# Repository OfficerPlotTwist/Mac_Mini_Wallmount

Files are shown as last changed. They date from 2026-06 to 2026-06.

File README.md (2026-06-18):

# Mac Mini M4 Wall Mount

A parametric, 3D-printable wall mount for the **Apple Mac Mini M4 / M4 Pro** (127 × 127 × 50 mm chassis), authored in **OpenSCAD**.

The Mini mounts flat against the wall with the **Apple logo facing the room**; the intake base + power button face the wall, held off by a ¾″ standoff gap. It's rotated 90° so the port faces meet the side rails — back ports (3× Thunderbolt, HDMI, Ethernet, power) on one rail, front (2× USB‑C, headphone) on the other.

## Design highlights

- **Corner‑hugging frame** — four rounded corner pockets cup the Mini's 25 mm corners; flexible side rails with snap hooks retain it in Z (press‑in assembly).
- **Side‑rail port cutouts** — obround holes sized per connector, widened for rubber strain‑relief boots, with inter‑port webs auto‑clamped to ≥ 3 perimeters.
- **Ø88 mm central contact pad** with a wide bore, reaching the Mini's solid central base past the recessed cooling vents.
- **Organic "topology‑optimized" bracing** — tapered Bézier struts fan from the pad to the side rails and corners (thick at the anchors, thin mid‑span).
- **Discrete support shelves** — small chamfered ledges, each sitting on a strut, at the recessed‑perimeter height.
- **Power‑button access pocket** — ribs beneath the wall‑facing power button shortened so a finger/tool can reach it.
- Four wall screws in the open top/bottom segments (clear driver access), countersunk for #8 wood screws / drywall anchors.

Target: **Prusa MK4**, 0.4 mm nozzle / 0.2 mm layer, **PETG**. A structural check (≈ 0.85 kg Mini, SF 10) leaves the load‑bearing wall at ~1.6 % of yield — the printed structure is far stronger than needed; wall anchors are the real limit.

## Files

| Path | What |
|---|---|
| `macmini_wall_mount.scad` | Parametric source (always the latest design) |
| `macmini_wall_mount.stl`  | Latest rendered mesh |
| `Macmini.glb` | Reference Mac Mini model (stylized — verify dims against a real unit) |
| `versions/` | Snapshots (`vNN_*.scad` + `.stl`), `thumbs/`, and `VERSIONS.md` change log |

## Build

```sh
openscad -o macmini_wall_mount.stl macmini_wall_mount.scad
```

Key parameters live at the top of the `.scad` (fit, standoff gap, wall thickness, port lists, strut/shelf controls, power‑button location). See `versions/VERSIONS.md` for the design evolution.

> **Before printing:** port positions and the power‑button location come from a *stylized* reference GLB — verify against your actual Mac Mini, and set `ridge_lift` to the measured perimeter recess depth.

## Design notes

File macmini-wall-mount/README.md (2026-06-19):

# Mac Mini M4 Wall Mount

A parametric, 3D-printable wall mount for the **Apple Mac Mini M4 / M4 Pro** (127 × 127 × 50 mm chassis), authored in **OpenSCAD**.

The Mini mounts flat against the wall with the **Apple logo facing the room**; the intake base + power button face the wall, held off by a ¾″ standoff gap. It's rotated 90° so the port faces meet the side rails — back ports (3× Thunderbolt, HDMI, Ethernet, power) on one rail, front (2× USB‑C, headphone) on the other.

## Design highlights

- **Corner‑hugging frame** — four rounded corner pockets cup the Mini's 25 mm corners; flexible side rails with snap hooks retain it in Z (press‑in assembly).
- **Side‑rail port cutouts** — obround holes sized per connector, widened for rubber strain‑relief boots, with **45° teardrop tops** (self‑supporting when printed back‑plate‑down — no droopy overhangs) and inter‑port webs auto‑clamped to ≥ 2.0 mm (~4–5 perimeters, so the crowded back‑rail webs don't snap).
- **Ø88 mm central contact pad** with a wide bore, reaching the Mini's solid central base past the recessed cooling vents.
- **Organic "topology‑optimized" bracing** — tapered Bézier struts fan from the pad to the side rails and corners (thick at the anchors, thin mid‑span).
- **Discrete support shelves** — small chamfered ledges, each sitting on a strut, at the recessed‑perimeter height.
- **Power‑button access pocket** — ribs beneath the wall‑facing power button shortened so a finger/tool can reach it.
- Four wall screws in the open top/bottom segments (clear driver access), countersunk for #8 wood screws / drywall anchors.

Target: **Prusa MK4**, 0.4 mm nozzle / 0.2 mm layer, **PETG**. A structural check (≈ 0.85 kg Mini, SF 10) leaves the load‑bearing wall at ~1.6 % of yield — the printed structure is far stronger than needed; wall anchors are the real limit.

## Files

| Path | What |
|---|---|
| `macmini_wall_mount.scad` | Parametric source (always the latest design) |
| `macmini_wall_mount.stl`  | Latest rendered mesh |
| `Macmini.glb` | Reference Mac Mini model (stylized — verify dims against a real unit) |
| `versions/` | Snapshots (`vNN_*.scad` + `.stl`), `thumbs/`, and `VERSIONS.md` change log |

## Build

```sh
openscad -o macmini_wall_mount.stl macmini_wall_mount.scad
```

Key parameters live at the top of the `.scad` (fit, standoff gap, wall thickness, port lists, strut/shelf controls, power‑button location). See `versions/VERSIONS.md` for the design evolution.

> **Before printing:** port positions and the power‑button location come from a *stylized* reference GLB — verify against your actual Mac Mini, and set `ridge_lift` to the measured perimeter recess depth.

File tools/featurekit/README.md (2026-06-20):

# featurekit

Feature-first CAD engine. Declare a part as an ordered list of named features
(each `add` or `cut`, each with a stable id and deterministic color); generate
a fused printable STEP plus a colored, labeled feature-view assembly + manifest
sidecar for the CAD Viewer's Feature Legend panel.

## Usage

```python
from pathlib import Path
from build123d import Box, Cylinder
from featurekit import Feature, Part, generate

p = Part("plate")
p.add(Feature(id="base_plate", name="Base plate", kind="add", build=lambda: Box(20, 20, 4)))
p.add(Feature(id="vent_hole", name="Vent hole", kind="cut", build=lambda: Cylinder(3, 10)))

generate(p, stem=Path("models/plate"))
# -> models/plate.step (fused, printable)
#    models/plate.features.step (colored feature-view assembly)
#    models/plate.features.step.js (legend manifest sidecar)
```

## Dev setup

```bash
pip install -r tools/featurekit/requirements.txt   # build123d for geometry
python -m pytest tools/featurekit/tests -v
```

Geometry tests are skipped automatically when build123d is not installed.

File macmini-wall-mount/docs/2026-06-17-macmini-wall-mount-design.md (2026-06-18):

# Mac Mini (M4 / M4 Pro) Wall Mount — Design Spec

**Date:** 2026-06-17
**Author:** Claude + supercoolraydude@gmail.com
**Target hardware:** Apple Mac Mini 2024 (M4 / M4 Pro) — shared 127 × 127 × 50 mm chassis
**Output:** One parametric OpenSCAD file → STL → PrusaSlicer (MK4) → printed in ASA

---

## 1. Goal

A single-piece, wall-mounted cradle that holds the Mac Mini **flat against the wall** while leaving the **rear ports + exhaust, the front ports, the bottom air intake, and the power button all usable**. Screw-mounts to the wall. No screw/VESA holes exist on the Mini, so retention is purely mechanical (edge capture).

## 2. Verified hardware facts

| Fact | Value | Source |
|---|---|---|
| Footprint | 127 × 127 mm (5 × 5 in) | Apple spec; GLB aspect ratio confirms 2.54:1 |
| Height | 50 mm (2 in) | Apple spec |
| Weight | ~0.67–0.73 kg | Apple spec |
| Back ports | power, Ethernet, HDMI, 3× Thunderbolt 4 | MacRumors / OWC |
| Front ports | 2× USB-C, headphone jack | MacRumors / OWC |
| Power button | **underside, rear-left corner** | MacRumors |
| Air intake | ring on the **bottom** face (perimeter of central base puck) | Apple design |
| Exhaust | out the **back** face | Apple design |
| Corner radius | **25 mm** (≈77 mm flat per side) | measured from `Macmini.glb`, all 4 corners |

The supplied `Macmini.glb` is geometrically a true Mac Mini but at an arbitrary scale (~38 units/m); it is **reference-only**. All dimensions come from Apple's published figures and are parameterized.

## 3. Orientation (locked)

Mini mounted flat against the wall:

- **Top / Apple-logo face → faces the room** (clean appearance).
- **Bottom face (intake + power button) → toward the wall**, held off the backplate by a central standoff.
- **Back edge (6 ports + exhaust) → faces DOWN** — cables route straight down the wall; exhaust vents downward.
- **Front edge (USB-C + headphone) → faces UP** — front ports remain reachable.
- **Standoff gap ≈ 28 mm** between bottom face and backplate: feeds the intake ring and gives whole-finger access to the power button.

### Coordinate convention (as mounted, viewer in the room)
- **+X** = viewer's right, **+Y** = up, **+Z** = out of wall toward viewer.
- Wall plane = XY at Z = 0 (backplate face).
- Derived power-button location: bottom face, **down edge (−Y), viewer's-right (+X) corner**, on the wall side. (Original rear-left maps to mounted lower-right after the logo-to-room / back-edge-down rotation. **To be confirmed against the physical unit**; position is parametric.)

```
 FRONT (from the room)                 SIDE (cross-section, gravity ↓)
 ┌───────────────────────┐ ← UP: front   wall│        room→
 │ o   ┌───────────┐   o │  USB-C+phones     │┌──┐
 │     │  ▲ Apple   │     │  (open)        B  │↕ ││M │ ← top/logo→room
 │     │   logo     │     │  ←L/R rails    P  │28││I │
 │     │(top face) │     │   +return lip  L  │mm││N │
 │ o   └───────────┘   o │ ← DOWN: back   E  │↕ ││I │ ← bottom face→wall
 └──────[button≈lower-R]─┘  ports+exhaust    │ s└──┘
   o = wall screw holes      (open)           standoff in gap
```

## 4. Part breakdown (single printed piece)

1. **Backplate** — flat plate against the wall. 4 countersunk screw holes (corners) for #8 wood screws / drywall anchors. Lightened/vented where it doesn't weaken the screw bosses. Thickness ~4–5 mm.
2. **Central standoff boss** — raised pad (height = gap ≈ 28 mm) contacting **only the Mini's central base puck**, never the intake ring. Sets the airflow/finger gap.
3. **Rounded capture frame** — full-height side walls conforming to the Mini's rounded corners (corner hug + in-plane retention incl. ~0.7 kg weight). The **top & bottom port edges are opened nearly corner-to-corner (~114 mm)** — independent of `corner_r` — because the back ports span almost the full width; only small corner nubs remain. The rounded-corner cut removes the arc material in front of the outer ports too.
4. **Side snap hooks** — on the flexible left & right straight rails, a **~2 mm flat catch** with a 45° self-supporting top, retaining the Mini in Z (pull-off). Rails **vented at gap level** for side airflow.
5. **Assembly** — press the Mini straight in toward the wall: corners drop into their pockets, side rails flex, hooks snap over the top-face edge.
6. **Power-button access** — lower-right, reached through the open bottom edge + 28 mm gap (wall-side gap kept clear there).
7. **Open zones (must stay clear):** full top/logo face; front ports (up edge); back ports + exhaust (down edge); intake gap behind; power button (lower-right).

## 5. Parameters (OpenSCAD variables, with defaults)

| Param | Default | Notes |
|---|---|---|
| `mini_w` | 127 | Mini width (X) |
| `mini_h` | 127 | Mini height (Y) |
| `mini_t` | 50 | Mini thickness (Z, wall→room) |
| `corner_r` | 25 | Mini rounded-corner radius (measured from GLB) |
| `port_post` | 7 | structure kept at each end of the open port edges; **sets the port-opening width** (= `mini_w + 2*fit − 2*port_post` ≈ 114 mm) independent of `corner_r` |
| `fit` | 0.4 | per-side clearance |
| `gap` | 28 | standoff height (intake + button access) |
| `lip_flat` | 2.0 | side-hook flat catch depth |
| `wall_th` | 3.2 | capture-wall thickness |
| `back_th` | 4.5 | backplate thickness |
| `ear` | 16 | side screw-ear width |
| `screw_d` | 4.5 | clearance for #8 screw shank |
| `head_d` | 9 | countersink head dia |
| `vent` | true | side-rail venting on/off |

## 6. Thermal rationale

- **Intake:** bottom ring draws from the 28 mm gap, fed by the open up edge, open down edge, and vented side rails — unobstructed.
- **Exhaust:** out the down edge, directed away from the cradle; minimal recirculation since intake is fed primarily from the up/side edges.
- **Material:** **ASA** (heat-tolerant, already in the user's filament stock). **PLA is rejected** — softens near the warm exhaust.

## 7. Print settings (target)

- Printer: Prusa MK4 (IS), 0.4 mm nozzle, 0.2 mm layers (matches existing prints on the USB).
- Orientation: backplate flat on the bed (+Z = out of wall); lips printed as chamfered overhangs → **no supports**.
- Material: ASA. Perimeters ≥ 3, infill ≥ 20% for rigidity at the rails.

## 8. Acceptance criteria

1. Mini slides in and is retained against pull-off and against sliding down (weight held).
2. All rear ports + exhaust accessible/unobstructed (down edge).
3. Both front ports + headphone accessible (up edge).
4. Bottom intake ring unobstructed; ≥ 28 mm clear gap to backplate.
5. Power button reachable without removing the Mini.
6. Mounts to wall via 4 screws; sits flat.
7. STL renders cleanly from the `.scad` (manifold, no errors) and slices support-free in PrusaSlicer.
8. Top/logo face fully visible except thin perimeter lips.

## 9. Open items / to verify

- **Power-button exact corner** — confirm lower-right mapping against the physical Mini before printing; adjust `pb_x/pb_y`.
- **Intake ring inner/outer diameter** — confirm the standoff pad stays inside the central puck and never caps the ring; refine pad diameter on first test print.
- **Fit clearance** — 0.4 mm nominal; validate with a corner test print before committing to the full part.

## 10. Toolchain

- **OpenSCAD** (installed via winget this session) authors `macmini_wall_mount.scad`.
- Render: `openscad -o macmini_wall_mount.stl macmini_wall_mount.scad`.
- Slice/print: PrusaSlicer → MK4, ASA profile.

---

*Note: working directory is not a git repository, so this spec is written to disk but not committed. Run `git init` to version it if desired.*

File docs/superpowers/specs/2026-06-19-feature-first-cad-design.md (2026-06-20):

# Feature-First CAD with a Live Legend Viewport — Design Spec

**Date:** 2026-06-19
**Status:** Draft for review
**Scope:** Modules 0–2 (manifest contract, `featurekit` generator + naming-rigor
enforcement, viewer Feature Legend panel + live-refresh).
**Explicitly out of scope:** any Mac Mini–specific port or part-specific content.
This spec delivers the reusable engine + viewer only.

Companion methodology:
[`docs/methodology/part-separation-vs-merged-whole.md`](../../methodology/part-separation-vs-merged-whole.md).

## 1. Problem

Today CAD parts are authored as a **merged whole**: every addition and removal is
fused into one anonymous solid (OpenSCAD `union`/`difference`, or the `cad`
skill's "one valid solid" STEP). After generation, individual features
(backplate, standoff, frame, port cuts…) are not addressable — they cannot be
colored, named, isolated, reviewed independently, or owned by separate agents.

We want an iterative **text-to-CAD** workflow where each feature is **distinct
geometry**: named, deterministically colored, individually isolatable, with
removals shown as translucent ghost cutters — all in a **continually-open
viewport** with a docked legend (color → name key) that **refreshes in place** as
the user iterates by text, while the real exported part stays a single printable
solid.

## 2. Decisions (locked)

| Decision | Choice |
|---|---|
| Authoring toolchain | build123d → STEP, on top of the installed `cad`/`cadpy` engine |
| Feature ↔ part relationship | **Viz layer over one fused part** (fused solid is the print source of truth) |
| Subtractive features | **Translucent ghost cutters** — each removal is its own colored, labeled solid in the feature view |
| Viewport interactivity | **Custom Feature Legend panel** (Approach B), built in upstream viewer source |
| Legend location | **Docked under the render**, following the existing file-sheet visual language |
| Ghost styling | **Feature-identity color is primary** (each feature its own stable hue); cuts rendered translucent/x-ray and tagged `cut` in the legend. Revisitable. |
| Viewer source | Build against upstream **`earthtojake/text-to-cad`** (`main`, top-level `viewer/`); rebuild `dist` and sync into the local skill runtime |
| Naming | **Enforced at generation time** (a gate, not a guideline) |

## 3. Architecture

Three modules joined by one contract (the Feature Manifest). Each module is
independently understandable and testable.

```
 author (Python)                generate                         view (browser)
┌────────────────┐   featurekit   ┌──────────────────────┐  cad-viewer  ┌──────────────────────┐
│ Feature list   │ ─────────────▶ │ part.step (fused)    │ ───────────▶ │ 3D canvas            │
│ id/name/kind/  │  (Module 1)    │ part.features.step   │  (Module 2)  │ ─ Feature Legend ──  │
│ color/build()  │                │ part.features.step.js│              │ swatch·name·add/cut  │
└────────────────┘                │  (manifest = Mod 0)  │              │ eye·solo·ghost·reset │
        ▲                         └──────────────────────┘              └──────────────────────┘
        │ naming-rigor gate (fails generation on violation)                     ▲
        └───────────────────────────────────────────────────────────────────────┘
                          live-refresh: regenerate → reload in place, keep camera + panel state
```

### 3.1 Module 0 — Feature Manifest (the shared contract)

The spine every other module reads/writes. A feature is:

| Field | Type | Rules |
|---|---|---|
| `id` | string | lowercase slug (`^[a-z0-9]+(?:[-_][a-z0-9]+)*$`), unique within a part. **STEP part label == this id.** |
| `name` | string | non-empty display name |
| `kind` | enum | `add` \| `cut` |
| `colorHex` | string | `#RRGGBB`, deterministic function of `id` unless explicitly pinned |

Serialized into the `.features.step.js` sidecar as `manifest.features: Feature[]`,
alongside the existing step-module manifest fields (`schemaVersion`,
`step.path`). The sidecar also sets diagnostic-color and ghost-on view defaults.
The manifest is the single source the panel renders from; the STEP labels are the
binding between manifest rows and 3D bodies.

### 3.2 Module 1 — `featurekit` (Python, on cadpy/build123d)

A small library + authoring convention. Lives with the `cad` skill's `cadpy`
package (new module `cadpy.featurekit`) so it reuses `AssemblyHelper`, labels,
colors, and STEP/GLB export.

**Authoring API (shape, not final signatures):**

```python
from cadpy.featurekit import Feature, Part

part = Part(name="widget")
part.add(Feature(id="base_plate", name="Base plate", kind="add",
                 build=lambda ctx: ...))            # returns a build123d solid
part.add(Feature(id="vent_holes", name="Vent holes", kind="cut",
                 build=lambda ctx: ...))            # cutter solid (positive volume)
part.generate("models/widget")                       # writes the three artifacts
```

**Two reductions from the one feature list:**

1. `solid()` → fuse all `add` solids, subtract all `cut` solids → one printable
   solid → `widget.step` (and optional STL/3MF via existing `cad` exports).
2. `feature_view()` → `AssemblyHelper` compound: each `add` = opaque colored
   labeled solid; each `cut` = its cutter solid, labeled, colored, with alpha
   (the ghost) → `widget.features.step` + GLB sidecar + `widget.features.step.js`.

**Deterministic color:** `colorHex = palette[stable_hash(id) % len(palette)]`,
from a curated, visually-distinct palette. Explicit `color=` pins override. Same
id ⇒ same color across regenerations and across agents.

**Naming-rigor gate (cross-cutting, enforced here):** before any geometry is
built, `featurekit` validates the feature list and **raises on violation**:
- missing/empty `id` or `name`;
- `id` not matching the slug regex;
- duplicate `id` within the part;
- `kind` not in `{add, cut}`;
- a `cut` builder that returns a non-solid / open surface;
- color drift (a pinned color that disagrees with a previously-recorded binding,
  if a lock file is present).
Errors name the offending feature and the rule. This gate is what makes parallel
authoring safe (see methodology §"Naming rigor").

**Outputs (deterministic, explicit targets):** `<stem>.step`,
`<stem>.features.step`, `<stem>.features.step.js`, plus GLB/topology sidecars the
viewer already consumes. No directory-wide generation.

### 3.3 Module 2 — Viewer: Feature Legend panel + live-refresh

Built in the upstream `viewer/` React+Three source, designed with the
`frontend-design` skill, matching the existing file-sheet visual language.

**Panel (docked under the canvas):** one row per `manifest.features` entry:
- color swatch (the feature's `colorHex`),
- `name`,
- `add`/`cut` chip,
- **eye** (hide/show this body),
- **solo** (isolate: hide all others).
Plus global controls: **Ghost cutters** master toggle (show/hide all `cut`
bodies), **Reset** (restore all visible + default camera), and a collapse handle.
Hover/selection highlights the corresponding body; rows map to assembly parts by
`id` (== STEP label).

**Live-refresh (state-preserving):** when `part.features.step` changes on disk
(the agent regenerated it), the viewer reloads geometry **in place** and
preserves: camera pose, per-feature visibility/solo state, and ghost toggle —
all keyed by feature `id` so a removed/added feature degrades gracefully.
Mechanism: a lightweight change signal from the backend (content-hash poll or
SSE on the active file) that triggers a geometry reload without a full page
reset. New ids appear with defaults; vanished ids drop from the panel.

**Build & sync:** clone `earthtojake/text-to-cad`, follow root `AGENTS.md` to run
the viewer dev server, implement the panel + refresh, rebuild `dist`, and sync
the produced bundle into the local skill runtime
(`.agents/skills/cad-viewer/scripts/viewer/dist` + `backend/server.mjs`). Record
the upstream commit the bundle was built from.

## 4. End-to-end data flow

1. Author declares features (Python) → `part.generate(stem)`.
2. `featurekit` runs the naming-rigor gate, then emits `part.step` (fused),
   `part.features.step` (assembly), and `part.features.step.js` (manifest).
3. The workflow hands `part.features.step` to `cad-viewer`, which starts/reuses
   the server and opens the bottom-docked legend.
4. User iterates by text → regenerate → viewer hot-reloads in place, preserving
   camera + panel state.
5. For manufacturing, `part.step` (the fused solid) is the export source; STL/3MF
   derive from it.

## 5. Naming-rigor enforcement (cross-cutting requirement)

The single most important invariant. One identity in four places:
`source builder name → STEP label → manifest id → legend row id`. Enforced by the
Module 1 gate (§3.2). Optional `features.lock.json` records id→color bindings so
color stability is verifiable across sessions and agents. Generation **fails
closed**: a naming violation produces no artifacts, never a quietly-wrong blob.

## 6. Parallel-agent workflow (why this exists)

The separation + naming gate makes a fleet workflow safe: agents claim feature
`id`s, each builds its feature(s) against the shared datum/coordinate contract and
returns solids, and the reducer composes deterministically into the fused part +
feature view. Per-feature snapshot/measure/diff enables independent review;
stable ids/colors keep the legend and reviewer mental-model intact across
recombination. This spec delivers the engine that this workflow runs on; the
fleet orchestration itself is a downstream use, not part of Modules 0–2.

## 7. Error handling

- **Naming violations:** fail generation with a feature-named, rule-named error.
- **Non-solid cutter:** rejected by the gate before composition.
- **Empty feature list / no `add` features:** error (nothing printable).
- **Viewer can't read manifest:** panel falls back to the stock assembly tree and
  reports the missing/!invalid sidecar; geometry still renders.
- **Live-refresh signal lost:** viewer keeps last geometry and surfaces a "stale"
  indicator rather than silently diverging from disk.

## 8. Testing & validation

- **Module 0:** schema validation tests (valid/invalid manifests; slug regex;
  duplicate ids; bad kind).
- **Module 1:** generate a **trivial 2-feature test part** (one `add`, one `cut`)
  and assert: fused `part.step` is one solid; `part.features.step` has exactly two
  labeled bodies with ids == labels; cutter carries alpha; colors deterministic
  across two runs; naming gate raises on each violation class. Validate geometry
  with `scripts/inspect refs --facts` and a `scripts/snapshot` packet.
- **Module 2:** load the test part's feature view; assert the panel renders two
  rows with correct swatch/name/add-cut; eye/solo/ghost/reset behave; regenerate
  the part and confirm camera + panel state persist and the changed body updates
  in place. Visual review via the running viewer.

The 2-feature test part is a generic fixture (e.g. a plate with a hole), **not**
a Mac Mini artifact.

## 9. Build phasing

0. **Lock the Feature Manifest contract** (schema + slug rules + sidecar shape).
1. **`featurekit` generator + naming-rigor gate**, validated on the trivial
   2-feature fixture (deterministic colors, dual output, sidecar).
2. **Viewer Feature Legend panel + live-refresh** in upstream source; rebuild and
   sync the bundle.

Each phase is independently verifiable; Module 2 depends only on the Module 0
contract and a sample feature-view artifact from Module 1.

## 10. Assumptions & open items

- `cadpy`'s color/alpha export reaches the viewer's GLB sidecar with per-part
  fidelity (grounded: `AssemblyHelper.add_part(..., color=...)` exists and the
  export path references color/alpha; confirm alpha round-trips during Phase 1).
- Upstream `viewer/` builds cleanly per root `AGENTS.md` on this Windows
  environment; if not, capture the blocker before committing to the bundle sync.
- Live-refresh transport (hash-poll vs SSE) chosen in Phase 2 based on what the
  backend already exposes; both preserve the same state-keyed-by-id behavior.
- Ghost styling default (identity-hue + translucent + `cut` tag) may be tuned
  after first visual review.

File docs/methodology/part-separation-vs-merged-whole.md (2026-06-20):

# Part-Separation vs Merged-Whole CAD Methodology

**For: parallel-agent CAD design, enforced by naming rigor**
**Date:** 2026-06-19
**Status:** Methodology reference (informs the feature-first CAD spec)

## Thesis

A 3D-printed part is one physical object, but the *process* that designs it does
not have to be one undifferentiated blob of geometry. The dominant scripting
approach today — fuse every addition and subtraction into a single solid (one
`union()`/`difference()` tree, one output solid) — is a **merged-whole**
methodology. It is simple for one author and fatal for many.

This document argues for a **part-separation** methodology: author each feature
as a named, independently-built solid with a stable identity, then *compose*
those features deterministically into both (a) the single fused printable part
and (b) a colored "feature view" for inspection. Separation is what makes
**parallel-agent design** safe, and **naming rigor** is the discipline that keeps
separation from collapsing back into a blob.

## The merged-whole methodology

**Definition.** One source artifact builds one solid. Features exist only as
transient expressions inside a boolean tree:

```scad
module mount() {
  difference() {
    union() { backplate(); standoff(); frame(); side_hooks(); join_walls(); }
    port_cuts(); screw_holes(); standoff_bore(); pb_cut(); air_holes();
  }
}
```

After evaluation there is no "standoff" and no "port cuts" — only a mesh. The
feature names live in comments and module definitions, not in the output.

**Where it shines.** Single author, single context, small parts, fast first
draft. Nothing to coordinate; the CSG engine does the work.

**Why it blocks scale.** Three structural problems, all caused by the same root
— *features are not addressable after composition*:

1. **No parallel ownership.** You cannot hand "the standoff" to one agent and
   "the port cuts" to another and recombine their work, because both are
   entangled in one boolean tree and collapse into one output solid. Merges are
   line-based text merges of a monolith — conflict-prone and semantically blind.
2. **No per-feature verification.** You cannot snapshot, measure, or diff a
   single feature in isolation; the viewer sees one anonymous mesh. "Is the
   power-button hole right?" requires reasoning about the whole.
3. **No stable identity across iterations.** When the model regenerates, there
   is nothing to key on — no id to preserve a color, a camera focus, or a
   reviewer's annotation against. Every iteration is a fresh blob.

## The part-separation methodology

**Definition.** Each feature is declared as a first-class object with a stable
`id`, a display `name`, a `kind` (`add` or `cut`), a deterministic `color`, and
a builder that returns one solid. A part is an *ordered list* of features.

Two deterministic reductions run from that one list:

- **Fused part** (`part.step`): union all `add` solids, subtract all `cut`
  solids → the single printable solid. This remains the manufacturing source of
  truth; nothing about separation changes what gets printed.
- **Feature view** (`part.features.step` + sidecar): an assembly compound where
  each `add` is an opaque colored labeled solid and each `cut` is its cutter
  solid rendered translucent (the "ghost"). The STEP part **label equals the
  feature id**, and a manifest sidecar carries `{id, name, kind, colorHex}`.

Separation is a *viz-and-process layer over one part*, not a multi-body part.
The fused output keeps it printable; the feature view makes it addressable.

## Why separation enables parallel-agent design

Separation turns geometry composition into a problem with **merge keys and
contracts** instead of text conflicts:

- **Features compose at datums, not at text lines.** Each agent builds its
  feature against a shared coordinate/datum contract and returns a solid. The
  reducer composes by union/subtract at well-defined positions — so two agents
  editing two features never collide in a shared monolith.
- **Stable ids are merge keys.** A feature id uniquely identifies a unit of work
  end-to-end: source builder → STEP label → legend row → reviewer annotation.
  Agents claim ids; the validator rejects collisions before geometry is built.
- **Per-feature isolation is verifiable.** Each agent's output is a single named
  solid that can be snapshotted, measured, and diffed independently, then
  composed. Review is per-feature, not per-blob.
- **Deterministic color = stable visual identity.** Color assigned by id (not by
  declaration order) means adding or reordering features never recolors existing
  ones, so a reviewer's mental map and a legend's swatches survive iteration.

In short: merged-whole scales to one author; part-separation scales to a fleet,
because the unit of work (a named feature) is the unit of ownership, the unit of
review, and the unit of recomposition.

## Naming rigor is the enabling discipline

Separation only holds if names are trustworthy. The moment ids drift, duplicate,
or go missing, the merge keys break and the methodology degrades back toward a
blob. Naming rigor is therefore not cosmetic — it is the load-bearing invariant.
The enforcement skill guarantees:

- **Presence:** every feature has a non-empty `id` and `name`.
- **Uniqueness:** ids are unique within a part (no silent overwrite on merge).
- **Slug form:** ids are lowercase kebab/snake slugs — safe as STEP labels, file
  keys, and URL/query fragments.
- **Traceability:** STEP part label == feature id == manifest id == source
  builder name. One identity, four places, no aliasing.
- **Kind validity:** `kind ∈ {add, cut}`; cutters must be solids (a removal is a
  positive solid used negatively, never an open surface).
- **Deterministic color binding:** color is a pure function of id (or an explicit
  pin), checked stable across regenerations.

Enforcement is an automated gate in the generator: violations **fail
generation** rather than producing a quietly-wrong blob. That gate is what lets
multiple agents work in parallel without a human refereeing every recombination.

## Trade-offs / costs

- **More structure up front.** You declare features and datums instead of
  free-handing one boolean tree. Pays off the first time two people/agents touch
  the part or you need to review one feature.
- **Double output.** Two reductions (fused + feature view) cost extra generation
  time and disk. Mitigated by sharing the same feature list and builders.
- **Overlap discipline.** Additive features may overlap at mating faces; that is
  fine for the fused part (boolean handles it) but means the feature view shows
  doubled material — acceptable as a viz layer, called out in the legend.

## Recommendation

Adopt part-separation as the default for any part that will be (a) designed by
more than one agent/author, (b) reviewed feature-by-feature, or (c) iterated
repeatedly by text. Keep merged-whole only for throwaway single-author sketches.
Make naming rigor a generation-time gate, not a guideline — it is the difference
between separation that scales and separation that rots.

See the implementation spec:
[`docs/superpowers/specs/2026-06-19-feature-first-cad-design.md`](../superpowers/specs/2026-06-19-feature-first-cad-design.md).

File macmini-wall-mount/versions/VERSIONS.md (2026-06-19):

# Mac Mini Wall Mount — Design Evolution

All dimensions in mm. Working source: `../macmini_wall_mount.scad` (always = latest).
Reference model: `../Macmini.glb` (M4 chassis, 127 × 127 × 50 mm).

| Ver | File | Key change |
|-----|---|---|
| v16 | `v16_teardrop-ports_thick-webs_pb-cleanup.scad` | **Current. Printability fixes.** (1) **Droopy port overhangs** — every port (obround + round) now gets a **45° teardrop gable** on top (`teardrop`, `port_profile2d`) so the printed-up ceiling never bridges horizontally; the converging gables also tie each thin inter-port web into the wall above. (2) **Snapped USB-C/Thunderbolt webs** — `web_min` 1.35 → **2.0 mm** (the crowded back-rail webs were exactly 1.35 mm = 3 perimeters and broke; now ~2.0 mm, ports ~0.6 mm narrower). (3) **Power-button boolean junk** — replaced the single-corner `pb_skip_a` drop with an angular keep-out `near_pb()` (`pb_dir`, `pb_keep=22`) that drops **every** strut/shelf reaching into the finger channel (the −X-rail strut the finger cylinder used to slice into stub geometry + the −X−Y corner fan), leaving the channel clean. Mesh verified single-solid (CGAL `Volumes: 2`). |
| v15 | `v15_airflow-vents_finger-corner-cleanup.scad` | **Airflow vents** (`airflow`, `air_*`): 8 holes bored through the backplate in the gaps between the radial struts (skipping the finger-hole corner). **Junk cleanup**: the finger cylinder ran along the −X,−Y corner and shredded that corner's fan into stub fragments → that one corner's fan + shelves are now dropped (`pb_skip_a`, auto-derived from the button angle = 180°). Also: project rescaled to **mm** in Blender and the GLB Mini reference reseated cleanly. |
| v14 | `v14_pbutton-side-finger-hole.scad` | The v13 backplate through-hole was useless mounted flush to a wall → replaced with a **finger hole through the curved corner SIDE wall** (`pb_finger=22`, `pb_z=20`): a horizontal channel aimed radially at the button (z-band ~9–31, reaching the press-face at z≈29), clearing the corner wall + struts in the path. Backplate stays solid; inner end clears the central pad by ~10 mm. |
| v13 | `v13_pbutton-through-hole.scad` | Power button faces the wall and was unreachable in the mount → `pb_cut` changed from a blind pocket to a **Ø20 through-hole** (`pb_r`) from the back face up to the button, clearing the backplate + struts/shelves in that column (pad & corner wall untouched). Assembly fit-check (Mini seated in harness from `Macmini.glb`) confirmed **no clipping**; contact gaps ~0.8–2 mm suggest `ridge_lift`≈4.5 — verify on a real unit. |
| v12 | `v12_corner-clip-fix_pbutton-pocket.scad` | **Fixed corner clipping** — struts+shelves now intersected with the outer footprint so their straight segments can't poke past the rounded corners. **Power button located** from the GLB ‘power button’ mesh (Mini seated in the harness): button at harness (−47.9, −47.9). Clearance changed to a **round access pocket** (`pb_x/pb_y/pb_r`) at that spot, ribs left 3 mm above the backplate base (`pb_rib_h`). |
| v11 | `v11_strut-shelves_pbutton-clearance.scad` | Continuous rest-ledge → **discrete chamfered shelves**, one per join strut (both rails + the swept corner walls) so each is cleanly supported by a rib beneath. **Power-button clearance**: the join ribs in a zone next to the back rail are shortened to **3 mm** (`pb_*` params — verify `pb_side`/`pb_y` on a real Mini). |
| v10 | `v10_organic-struts_wide-bore.scad` | Big jump from v09 (intervening work consolidated): side ports widened for rubber boots (width web-clamped to 3 perims), **Ø88 mm central pad**, 4 screws → **open top/bottom segments**, rest-ridges **lifted** (`ridge_lift`), top/bottom walls **swept past corners** (`corner_sweep`), central **bore widened to 72 mm**, and **full-height organic "topology-optimized" struts** (fans to the side rails + corners) replacing the solid pad and the thick diagonal ribs. Material now **PETG**. |
| v01 | `v01_straight-rails_ports-down.scad` | First design. Straight L/R capture rails, **square corners**, back ports exit a rectangular opening on the **down** edge. Snap hooks + bottom corner ledges. Screw ears. |
| v02 | `v02_corner-hug_narrow-open.scad` | **Corner-hugging**: rounded-rect frame conforming to the Mini's 25 mm corners; four corner pockets retain it. Port opening tied to `corner_r` (~77 mm, **too narrow** — clipped outer ports). |
| v03 | `v03_corner-hug_wide-open_screw-ears.scad` | Port opening **decoupled** from corner radius via `port_post` (~114 mm, clears all ports). Screw ears still present. |
| v04 | `v04_short-spacer_no-vents_min-footprint.scad` | Back spacer (standoff) → **¾″ (19.05 mm)**; side **airflow vents removed**; **screw ears removed** → footprint minimized to the frame (≈134 mm sq), 4 screws relocated **inside** the footprint. |
| v09 | `v09_chamfered-rest-ridges.scad` | Corrected which catch got chamfered: snap **hooks reverted** to original; the **lower rest ridges** now have a **45° chamfered underside** (self-supporting). Obround ports + bored/lightened plate carried over. |
| v08 | `v08_print-in-place_chamfer-catch_round-ports.scad` | **Print‑in‑place (back on bed):** catch ledges **45° chamfered** (self‑supporting hooks), port holes **widened + rounded to obround** (`port_grow`). Standoff **bored through** the plate; plate **lightened** (4 windows). Blender cut now uses the *exact* OpenSCAD obround cutters (via `show_cutters` output mode). |
| v07 | `v07_bored-standoff_lightened-plate.scad` | Standoff bored clean through the backplate; wall plate lightened with 4 windows. |
| v06 | `v06_rest-ridges_inner-screws_hollow-standoff.scad` | Added **rest ridges** on the side rails (Mini base sits on them); **screws moved ½″ toward centre** (`screw_xy` 53→40.3); **standoff hollowed** (4 mm ring wall). LED at the loop-selected spot (`led_y=24.4, led_z=45.7`). |
| v05 | `v05_side-ports_led.scad` | All **9 ports cut into the side rails** (parametric, in OpenSCAD): 6 back (3×TB, HDMI, Ethernet, power) on the −X rail, 3 front (2×USB-C + headphone) on the +X rail, **+ power-LED hole** (front-left, `led_y/led_z/led_d` — estimated, not in the GLB). Port band `port_z = zmb + 22`. |

## Parameter diffs (v03 → v04)
- `gap`: 28 → **19.05** (¾ inch)
- `vent`: true → **false**
- screw mounting: outboard ears (`ex = ow/2 + ear/2`) → **inboard** (`screw_xy = 53`, within footprint)
- `backplate()`: rounded body **+ ears** → rounded body only

## Blender-MCP branch (port-traced cutouts)
Parallel exploration using the real GLB ports (not yet merged into the parametric `.scad`):
- `blender_port-traced.stl` — ports **traced** from the GLB (bisect each opening → convex hull → 1 mm offset → extrude), cut as port-shaped holes into **closed panels** on the top/bottom edges.
- Then re-oriented per request: **logo faces room**, Mini **rotated 90°** so ports land on the **side rails (with clips)**; back ports (3×TB, HDMI, Ethernet, power) on one side, front (2×USB-C + headphone) on the other.
- ✅ Blender boolean **does work** here — via `bpy.ops.object.modifier_apply` inside a `temp_override`. (The earlier failure was the *method*: `evaluated_get(depsgraph)` + `new_from_object` silently no-ops in this MCP context. `modifier_apply` mutates the mesh directly and works.)
- `v05b_blender-boolean-cut.stl` — the v05 base with all 9 ports + LED cut by **Blender's boolean** (rect cutters + round headphone/LED), cleaned to watertight. Equivalent to the OpenSCAD `v05` part.

## Traced port footprints (for OpenSCAD side-rail cutouts)
Ports arranged along Y on the ±X side faces, +1 mm clearance. Z is relative to the Mini's wall-side (intake) face; re-derive absolute Z from `gap`.
- **Back (−X):** TB1/2/3 each 4.7 (Y) × 10.5 (Z); HDMI 17.1 × 7.0; Ethernet 14.6 × 12.6; Power 19.1 × 10.7.
- **Front (+X):** USB-C ×2 each 4.7 × 10.5; Headphone ⌀6.2.
- Port band sat ~22 mm above the intake face (centre), spanning ~11 mm tall.

## Caveat
The GLB is a **stylized** visualization model (TB ports drawn as vertical slits, 25 mm corners look large). Verify port sizes/positions against a real Mac Mini before printing.

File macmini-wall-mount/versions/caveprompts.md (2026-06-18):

# CAVE PROMPTS — Ugg Build Box-Holder for Wall

Same versions as `PROMPTS.md`, but Ugg speak. Each prompt = one caveman haiku.

---

## Setup — `Macmini.glb`
> Magic slab in stick
> Ugg pull picture from the bone
> drag back to my cave

---

## v01 — `v01_straight-rails_ports-down`
> Hang box on cave wall
> keep all hole and breath-slit free
> button still must poke

*(Ugg also grunt: flat on wall · button face stone · screw through · big-hole side down · gap wide · make fire-slab now)*

---

## v02 — `v02_corner-hug_narrow-open`
> Box have soft round edge
> make the cradle hug it tight
> no sharp, no gap — good

---

## v03 — `v03_corner-hug_wide-open_screw-ears`
> Hole no kiss the plug
> Ugg angry, mouth miss the mouth
> move so plug go in

---

## blender_port-traced — `blender_port-traced.stl`
> Trace true the plug-shapes
> grow them, push them, punch the wall
> use spirit Blender

---

## v04 — `v04_short-spacer_no-vents_min-footprint`
> Push box close to wall
> shut wind-hole, shrink the flat slab
> keep every old skin

---

## v05 — `v05_side-ports_led`
> Spin box quarter-turn
> apple-face look out at cave
> poke small glow-eye hole

---

## v05b — `v05b_blender-boolean-cut`
> Stone-tool still can cut
> Ugg wrong — Blender make the hole
> cut it for fire-slice

---

## v06 — `v06_rest-ridges_inner-screws_hollow-standoff`
> Add little ledge-shelf
> walk bone-pins toward the middle
> scoop fat post hollow

---

## v07 — `v07_bored-standoff_lightened-plate`
> Punch post all the way
> chew light holes in heavy plate
> Ugg use less of mud

---

## v08 — `v08_print-in-place_chamfer-catch_round-ports`
> Round the plug-mouths wide
> back flat on the hot rock-bed
> build with no crutch-stick

---

## v09 — `v09_chamfered-rest-ridges`  ← Ugg here now
> No! not that ledge, fool
> slope the under-lip below
> so it stand alone

---

*Ugg done. Box go on wall. Mini sleep good. Fire-slice the bone-shape soon.*

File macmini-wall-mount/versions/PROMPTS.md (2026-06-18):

# Mac Mini Wall Mount — Versions & the Prompts That Created Them

Every saved model in `versions/` paired with the user prompt(s) that drove it (quoted verbatim).
`vNN` = parametric OpenSCAD (`.scad` + `.stl`); `vNNb` = the same design produced via Blender's boolean (`.stl`).

---

## Setup
> **"extract mac mini model off pruda usb to here"**

Pulled `Macmini.glb` off the PRUSA USB into the project (used thereafter as the dimensional reference / port-trace source).

---

## v01 — `v01_straight-rails_ports-down`
> **"I want to model a wall mount that leaves ports , powerbutton, and cooling ducts on the back exposed"**

Brainstorm answers that shaped it:
> **"flat against wall"**
> *(retention)* **"bottom face with button towards wall, back spacer on the center give room for power button to be accessed"**
> *(wall mount)* **"Screw-through holes"**
> *(ports edge)* **"there are ports on top and bottom but side with more ports down"**
> *(gap)* **"Widen the gap"** · *(toolchain)* **"Install + render STL"**
> **"do it"** · **"go"**

→ First design: straight L/R capture rails, **square corners**, back ports out a rectangular opening on the **down** edge, snap hooks + bottom corner ledges, screw ears, 28 mm standoff.

---

## v02 — `v02_corner-hug_narrow-open`
> **"hug the profile of the rounded corners"**

→ Rounded-rect frame conforming to the Mini's 25 mm corners (corner pockets retain it). Opening tied to corner radius (~77 mm — too narrow).

---

## v03 — `v03_corner-hug_wide-open_screw-ears`
> **"the slots do not line up with the ports"**

→ Port opening **decoupled** from the corner radius (`port_post`, ~114 mm) so all rear ports clear.

---

## blender_port-traced — `blender_port-traced.stl`
> **"in mcp of your choice of rhino or blender, I want you to trace an offset of the ports on the mac mini model, extrude those, and make the cut that way."**
> *(which MCP)* **"https://github.com/ahujasid/blender-mcp.git do it"**

Loop-select dialogue while tracing:
> **"identify currently selected edge loops for the first side. verify no loops dipped below the surface edge"**
> **"deselect edges off the primary plane for me"**
> **"ethernet doesn't look broken unless on edge segment is missing where I don't see"**
> **"do that"** *(auto-close the loops)* · **"reace and extruce backside"** *(trace + extrude back)*

→ Real GLB ports traced (bisect → convex hull → 1 mm offset → extrude) and cut as port-shaped holes into closed panels on the top/bottom edges.

---

## v04 — `v04_short-spacer_no-vents_min-footprint`
> **"close airflow holes. reduce back spacer to 3/16 inch"** → **"no, 1/2 inch"** → **"no, 3/4 inch"**
> **"minimize wall plate footprint. remove screw tabes and move screwholes to within that footprint"**
> **"save all versions of design as it evolved"**

→ Spacer → ¾″ (19.05 mm); vents removed; ears removed → footprint minimized, 4 screws moved inside it. (And this `versions/` archive was created.)

---

## v05 — `v05_side-ports_led`
> **"rotate mini 90 degrees so port cutouts will be in the existing sides with clips. also flip around so apple logo faces away from the wall"**
> **"cut the ports into the side rails then make those other changes"**
> **"add a hole for the power light"**
> **"cutout for power light missing. very small circle with no inlay on the side with 3 cuts"**
> **"no, bring back the mac mini model and I'll loop select"** · **"selected"**

→ Logo faces the room; all 9 ports cut into the **side rails** (6 back / 3 front) + the **LED** hole loop-selected off the model (front, between USB-C and headphone).

---

## v05b — `v05b_blender-boolean-cut`
> **"blender has boolean capabilities do it after adding power light cutout"**
> **"we're slicing blender. update blender model"**

→ Same v05 design produced through Blender's boolean (`modifier_apply` in a `temp_override`). From here on, every version also gets a Blender cut (`vNNb`).

---

## v06 — `v06_rest-ridges_inner-screws_hollow-standoff` (+ `v06b`)
> **"add ridge rest on the side pieces. move screws in a half inch towards the center. hollow out the round spacer"**

→ Rest ridges on the side rails; screws moved ½″ inward (53→40.3); standoff hollowed to a 4 mm ring.

---

## v07 — `v07_bored-standoff_lightened-plate` (+ `v07b`)
> **"is clip overhang printable if printed in place?"** *(question — discussed, no change)*
> **"looks fine. the hollow support should cut all the way through the base plate."**
> **"use less material on the base"**

→ Standoff bore taken **clean through** the wall plate; plate **lightened** with 4 windows.

---

## v08 — `v08_print-in-place_chamfer-catch_round-ports` (+ `v08b`)
> **"camfer catch ledges, widen and round port holes so bracket is print in place with the back on the print bed"**

→ Port holes widened + rounded to **obround**; (catch chamfer applied to the snap hooks — corrected in v09). Blender cut switched to using the exact OpenSCAD obround cutter solids.

---

## v09 — `v09_chamfered-rest-ridges` (+ `v09b`)  ← current
> **"not thos ledges. camfer the lower catch edges"**

→ Snap hooks **reverted**; the **lower rest ridges** get the 45° chamfered underside (self-supporting, back-on-bed print).

---

### Also asked along the way (no new version)
> **"where is the addon locally?"** · **"show me the mac mini with port cutouts"**

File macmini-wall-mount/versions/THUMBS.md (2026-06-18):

# Visual Index — Mac Mini Wall Mount Versions

Thumbnails in `thumbs/`. Full prompts in `PROMPTS.md` · cave version in `caveprompts.md` · changelog in `VERSIONS.md`.

| | Version | What changed | Cave grunt |
|---|---|---|---|
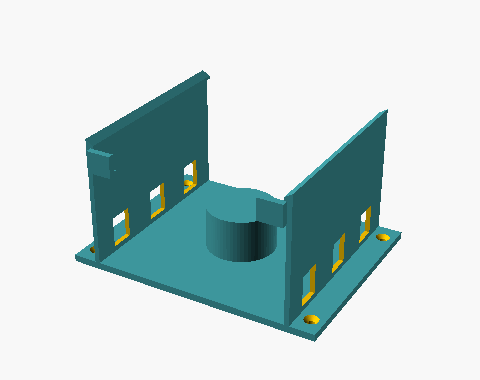
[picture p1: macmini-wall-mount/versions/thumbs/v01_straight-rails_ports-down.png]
v01
|  | **v01** straight-rails, ports-down | first design: square corners, ports out the down edge | *keep all hole and breath-slit free* |
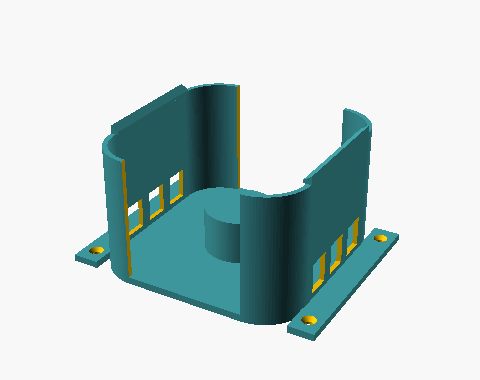
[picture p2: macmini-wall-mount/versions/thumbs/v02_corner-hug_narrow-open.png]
v02
|  | **v02** corner-hug, narrow | rounded frame hugs the 25 mm corners | *make the cradle hug it tight* |
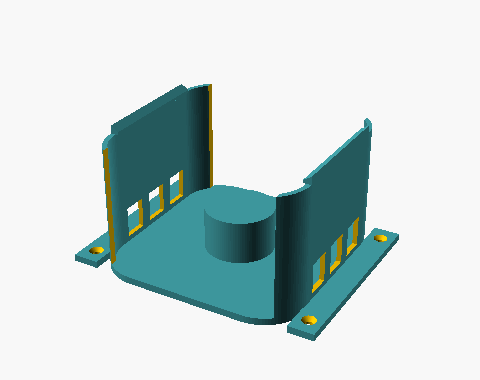
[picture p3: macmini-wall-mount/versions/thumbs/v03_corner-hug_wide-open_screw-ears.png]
v03
|  | **v03** wide-open ports | opening widened so ports clear | *move so plug go in* |
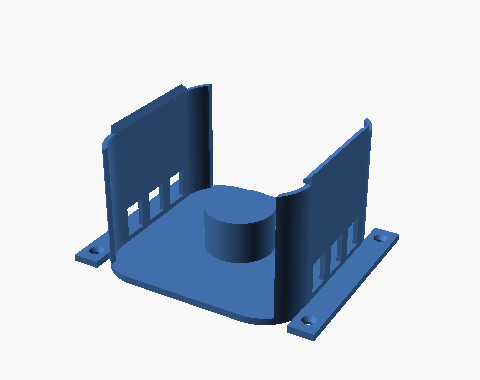
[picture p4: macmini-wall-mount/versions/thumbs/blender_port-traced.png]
bpt
|  | **blender_port-traced** | real ports traced in Blender → panel cutouts | *use spirit Blender* |
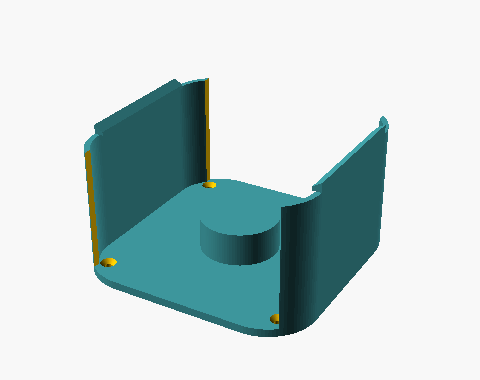
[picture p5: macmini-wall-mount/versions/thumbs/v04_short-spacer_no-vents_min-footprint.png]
v04
|  | **v04** short spacer / min footprint | ¾″ spacer, no vents, ears gone, screws inside | *shut wind-hole, shrink the flat slab* |
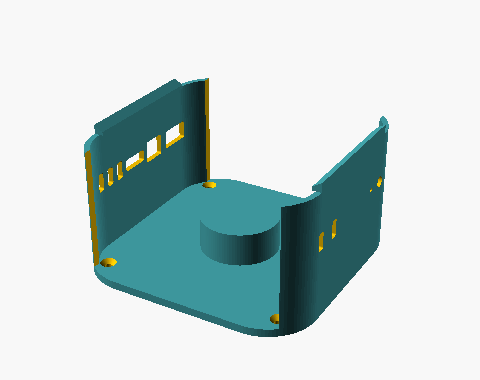
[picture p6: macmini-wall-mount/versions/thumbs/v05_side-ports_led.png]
v05
|  | **v05** side ports + LED | rotated 90°, ports in the rails, LED added | *poke small glow-eye hole* |
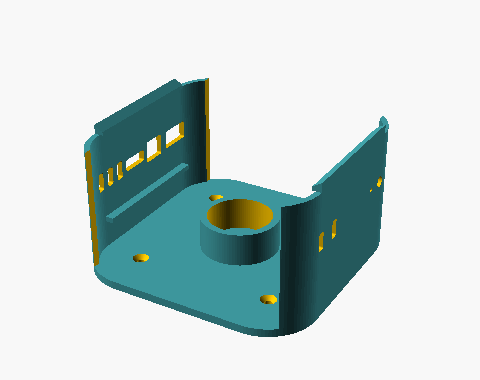
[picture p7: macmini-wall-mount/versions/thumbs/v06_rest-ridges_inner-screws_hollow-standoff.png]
v06
|  | **v06** ridges / hollow post | rest ridges, screws in ½″, hollow standoff | *scoop fat post hollow* |
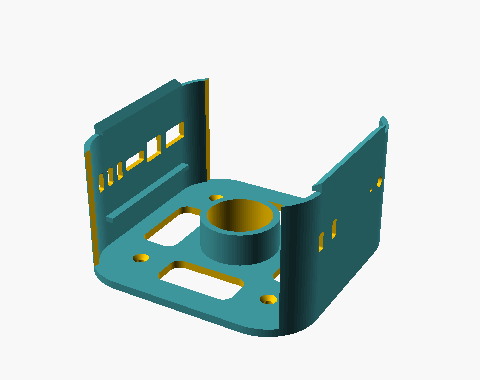
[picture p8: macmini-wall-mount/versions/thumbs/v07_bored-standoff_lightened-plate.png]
v07
|  | **v07** bored + lightened | bore through plate, 4 lightening windows | *Ugg use less of mud* |
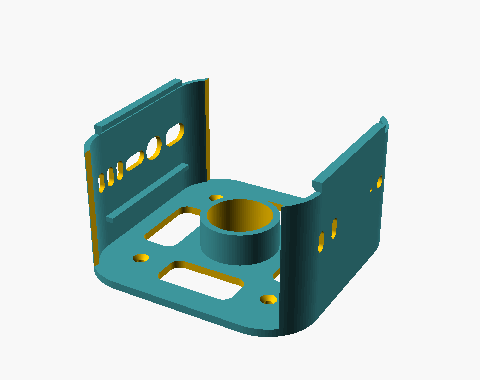
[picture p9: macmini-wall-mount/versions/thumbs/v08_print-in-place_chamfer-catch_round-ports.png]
v08
|  | **v08** obround ports | ports rounded/widened for print-in-place | *build with no crutch-stick* |
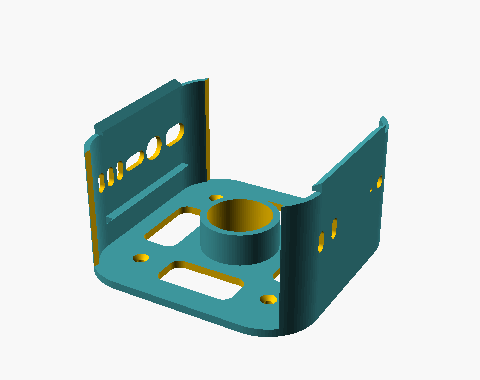
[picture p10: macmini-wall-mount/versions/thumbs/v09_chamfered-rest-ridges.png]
v09
|  | **v09** chamfered rest ridges ← current | lower ledges chamfered self-supporting | *so it stand alone* |

*(The `vNNb` files are the same designs cut with Blender's boolean — visually identical to their `vNN` thumbnail.)*

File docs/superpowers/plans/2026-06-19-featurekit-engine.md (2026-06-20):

# featurekit Engine (Modules 0–1) Implementation Plan

> **For agentic workers:** REQUIRED SUB-SKILL: Use superpowers:subagent-driven-development (recommended) or superpowers:executing-plans to implement this plan task-by-task. Steps use checkbox (`- [ ]`) syntax for tracking.

**Goal:** Build the Python `featurekit` engine that turns one feature list into a fused printable STEP plus a colored, labeled feature-view assembly + a manifest sidecar, with naming rigor enforced as a generation-time gate.

**Architecture:** A standalone local package `tools/featurekit/` imports the installed `cadpy`. A pure-Python core (manifest contract, slug naming gate, deterministic id→color, sidecar emission) carries the naming-rigor value and is testable without build123d. A thin geometry adapter uses `cadpy`/`build123d` to produce the two reductions: `solid()` (fuse adds, subtract cuts) and `feature_view()` (a list of labeled, colored solids — adds opaque, cuts translucent) that the existing `scripts/step` CLI renders into STEP + GLB.

**Tech Stack:** Python 3.12, pytest 9, build123d (geometry), cadpy (`AssemblyHelper`, `label_shape`), the `cad` skill's `scripts/step` generator pipeline.

## Global Constraints

- Python target: **3.12** (matches local `python` 3.12.10).
- `featurekit` lives at **`tools/featurekit/`** and imports the installed cadpy from `.agents/skills/cad/scripts/packages/cadpy/src` (added to `sys.path` via `tests/conftest.py`); never edit the vendored `cadpy` files. (Refinement of the spec's "cadpy.featurekit" wording — keeps our code out of vendored skill dirs that get overwritten on skill update.)
- Feature `id` slug regex: **`^[a-z0-9]+(?:[-_][a-z0-9]+)*$`** (verbatim from spec §3.1).
- Feature `kind` ∈ **`{"add", "cut"}`** (verbatim).
- `colorHex` format: **`#RRGGBB`** uppercase hex; deterministic function of `id` unless explicitly pinned.
- Color determinism MUST use **`hashlib.sha1`**, never builtin `hash()` (which is salted per-process).
- STEP part **label == feature id** (the binding the viewer maps rows to bodies by).
- Generation **fails closed**: any naming violation raises before geometry is built; no artifacts written.
- Cutter (`kind == "cut"`) ghost alpha: **0.35**; additive alpha: **1.0**.
- `docs`/`tools` are gitignored by the repo's allowlist `.gitignore`; add `!tools` exception in the scaffold task.

---

### Task 1: Package scaffold + dependency install + cadpy import seam

**Files:**
- Create: `tools/featurekit/featurekit/__init__.py`
- Create: `tools/featurekit/tests/conftest.py`
- Create: `tools/featurekit/README.md`
- Create: `tools/featurekit/requirements.txt`
- Modify: `.gitignore` (add `!tools`)

**Interfaces:**
- Consumes: nothing.
- Produces: importable package `featurekit`; `tests/conftest.py` puts the vendored cadpy `src` on `sys.path` so `import cadpy` works in tests.

- [ ] **Step 1: Add the gitignore exception**

In `.gitignore`, directly after the `!docs` line added earlier, add:

```gitignore
# Feature-first CAD engine (local package)
!tools
```

- [ ] **Step 2: Create the package + conftest + deps**

`tools/featurekit/featurekit/__init__.py`:

```python
"""featurekit — feature-first CAD: one feature list -> fused part + colored feature view."""

__all__ = []
```

`tools/featurekit/tests/conftest.py`:

```python
import sys
from pathlib import Path

# Make the local featurekit package importable.
PKG_ROOT = Path(__file__).resolve().parents[1]
if str(PKG_ROOT) not in sys.path:
    sys.path.insert(0, str(PKG_ROOT))

# Make the installed (vendored) cadpy importable for geometry tests.
REPO_ROOT = PKG_ROOT.parents[1]
CADPY_SRC = REPO_ROOT / ".agents" / "skills" / "cad" / "scripts" / "packages" / "cadpy" / "src"
if CADPY_SRC.is_dir() and str(CADPY_SRC) not in sys.path:
    sys.path.insert(0, str(CADPY_SRC))
```

`tools/featurekit/requirements.txt`:

```text
build123d>=0.7
```

`tools/featurekit/README.md`:

```markdown
# featurekit

Feature-first CAD engine. Declare a part as an ordered list of named features
(each `add` or `cut`, each with a stable id and deterministic color); generate
a fused printable STEP plus a colored, labeled feature-view assembly + manifest
sidecar for the CAD Viewer's Feature Legend panel.

## Dev setup

```bash
pip install -r tools/featurekit/requirements.txt   # build123d for geometry
python -m pytest tools/featurekit/tests -v
```

Geometry tests are skipped automatically when build123d is not installed.
```

- [ ] **Step 3: Verify the package imports and cadpy is reachable from tests**

Run: `cd tools/featurekit && python -c "import sys; sys.path.insert(0,'.'); import featurekit; print('ok')"`
Expected: prints `ok`.

Run: `python -m pytest tools/featurekit/tests -q`
Expected: `no tests ran` (collection succeeds, conftest imports cleanly).

- [ ] **Step 4: Commit**

```bash
git add .gitignore tools/featurekit
git commit -m "feat(featurekit): scaffold package + cadpy import seam"
```

---

### Task 2: Slug naming gate

**Files:**
- Create: `tools/featurekit/featurekit/naming.py`
- Test: `tools/featurekit/tests/test_naming.py`

**Interfaces:**
- Consumes: nothing.
- Produces:
  - `SLUG_RE: re.Pattern` — compiled `^[a-z0-9]+(?:[-_][a-z0-9]+)*$`.
  - `class NamingError(ValueError)`.
  - `validate_slug(value: str, *, field: str = "id") -> str` — returns the slug or raises `NamingError` naming the field and value.

- [ ] **Step 1: Write the failing test**

`tools/featurekit/tests/test_naming.py`:

```python
import pytest

from featurekit.naming import NamingError, validate_slug

@pytest.mark.parametrize("good", ["base_plate", "vent-holes", "m3", "a1-b2_c3"])
def test_validate_slug_accepts_valid(good):
    assert validate_slug(good) == good

@pytest.mark.parametrize("bad", ["", "Base", "base plate", "-x", "x-", "x__y" "@", "Ünïcode"])
def test_validate_slug_rejects_invalid(bad):
    with pytest.raises(NamingError):
        validate_slug(bad)

def test_naming_error_names_field_and_value():
    with pytest.raises(NamingError) as exc:
        validate_slug("Bad Id", field="id")
    msg = str(exc.value)
    assert "id" in msg and "Bad Id" in msg
```

- [ ] **Step 2: Run test to verify it fails**

Run: `python -m pytest tools/featurekit/tests/test_naming.py -v`
Expected: FAIL — `ModuleNotFoundError: No module named 'featurekit.naming'`.

- [ ] **Step 3: Write minimal implementation**

`tools/featurekit/featurekit/naming.py`:

```python
"""Slug naming gate — the load-bearing invariant for feature ids."""
from __future__ import annotations

import re

SLUG_RE = re.compile(r"^[a-z0-9]+(?:[-_][a-z0-9]+)*$")

class NamingError(ValueError):
    """Raised when a feature name/id violates the naming rules."""

def validate_slug(value: str, *, field: str = "id") -> str:
    """Return value if it is a valid lowercase slug, else raise NamingError."""
    if not isinstance(value, str) or not value:
        raise NamingError(f"feature {field} must be a non-empty string, got {value!r}")
    if not SLUG_RE.match(value):
        raise NamingError(
            f"feature {field} {value!r} is not a valid slug "
            f"(lowercase letters/digits, single - or _ separators): {SLUG_RE.pattern}"
        )
    return value
```

- [ ] **Step 4: Run test to verify it passes**

Run: `python -m pytest tools/featurekit/tests/test_naming.py -v`
Expected: PASS (all parametrized cases).

- [ ] **Step 5: Commit**

```bash
git add tools/featurekit/featurekit/naming.py tools/featurekit/tests/test_naming.py
git commit -m "feat(featurekit): slug naming gate"
```

---

### Task 3: Deterministic id→color palette

**Files:**
- Create: `tools/featurekit/featurekit/color.py`
- Test: `tools/featurekit/tests/test_color.py`

**Interfaces:**
- Consumes: nothing.
- Produces:
  - `PALETTE: tuple[str, ...]` — curated, visually distinct `#RRGGBB` colors.
  - `feature_color(feature_id: str) -> str` — deterministic `#RRGGBB` via `hashlib.sha1(id) % len(PALETTE)`.
  - `normalize_hex(value: str) -> str` — validates/upcases an explicit `#RRGGBB` pin, raises `ValueError` on bad format.

- [ ] **Step 1: Write the failing test**

`tools/featurekit/tests/test_color.py`:

```python
import re

import pytest

from featurekit.color import PALETTE, feature_color, normalize_hex

HEX = re.compile(r"^#[0-9A-F]{6}$")

def test_palette_is_distinct_valid_hex():
    assert len(PALETTE) >= 12
    assert len(set(PALETTE)) == len(PALETTE)
    assert all(HEX.match(c) for c in PALETTE)

def test_feature_color_is_deterministic_and_in_palette():
    a = feature_color("base_plate")
    b = feature_color("base_plate")
    assert a == b
    assert a in PALETTE

def test_feature_color_stable_across_added_ids():
    # Adding a new id must not change an existing id's color (hash-keyed, not order-keyed).
    before = feature_color("standoff")
    _ = feature_color("a-brand-new-feature")
    assert feature_color("standoff") == before

def test_normalize_hex_upcases_and_validates():
    assert normalize_hex("#aabbcc") == "#AABBCC"
    with pytest.raises(ValueError):
        normalize_hex("aabbcc")  # missing '#'
    with pytest.raises(ValueError):
        normalize_hex("#xyzxyz")
```

- [ ] **Step 2: Run test to verify it fails**

Run: `python -m pytest tools/featurekit/tests/test_color.py -v`
Expected: FAIL — `ModuleNotFoundError: No module named 'featurekit.color'`.

- [ ] **Step 3: Write minimal implementation**

`tools/featurekit/featurekit/color.py`:

```python
"""Deterministic, order-independent id -> color assignment."""
from __future__ import annotations

import hashlib
import re

_HEX_RE = re.compile(r"^#[0-9a-fA-F]{6}$")

# Curated, visually distinct palette (no near-duplicates, readable on a dark viewport).
PALETTE: tuple[str, ...] = (
    "#4E79A7", "#F28E2B", "#59A14F", "#E15759",
    "#76B7B2", "#EDC948", "#B07AA1", "#FF9DA7",
    "#9C755F", "#BAB0AC", "#1B9E77", "#D95F02",
    "#7570B3", "#E7298A", "#66A61E", "#E6AB02",
)

def normalize_hex(value: str) -> str:
    """Validate and upper-case an explicit '#RRGGBB' color pin."""
    if not isinstance(value, str) or not _HEX_RE.match(value):
        raise ValueError(f"color must be '#RRGGBB' hex, got {value!r}")
    return "#" + value[1:].upper()

def feature_color(feature_id: str) -> str:
    """Deterministic palette color for a feature id (stable across processes/runs)."""
    digest = hashlib.sha1(feature_id.encode("utf-8")).digest()
    index = int.from_bytes(digest[:4], "big") % len(PALETTE)
    return PALETTE[index]
```

- [ ] **Step 4: Run test to verify it passes**

Run: `python -m pytest tools/featurekit/tests/test_color.py -v`
Expected: PASS.

- [ ] **Step 5: Commit**

```bash
git add tools/featurekit/featurekit/color.py tools/featurekit/tests/test_color.py
git commit -m "feat(featurekit): deterministic id->color palette"
```

---

### Task 4: Feature + Part model with the naming-rigor gate

**Files:**
- Create: `tools/featurekit/featurekit/model.py`
- Modify: `tools/featurekit/featurekit/__init__.py`
- Test: `tools/featurekit/tests/test_model.py`

**Interfaces:**
- Consumes: `validate_slug`/`NamingError` (Task 2), `feature_color`/`normalize_hex` (Task 3).
- Produces:
  - `@dataclass class Feature` with fields `id: str`, `name: str`, `kind: str`, `build: Callable[[], Any]`, `color: str | None = None`.
  - `class Part`: `__init__(self, name: str)`; `add(self, feature: Feature) -> Feature`; `validate(self) -> None`; `features: list[Feature]`; `manifest(self) -> list[dict]` where each dict is `{"id","name","kind","colorHex"}`.
  - `class FeatureValidationError(NamingError)`.
  - `resolved_color(feature: Feature) -> str` helper (pin via `normalize_hex` else `feature_color(id)`).

- [ ] **Step 1: Write the failing test**

`tools/featurekit/tests/test_model.py`:

```python
import pytest

from featurekit.model import Feature, FeatureValidationError, Part

def _f(fid, kind="add", name=None, color=None):
    return Feature(id=fid, name=name or fid.replace("_", " ").title(),
                   kind=kind, build=lambda: object(), color=color)

def test_manifest_shape_and_deterministic_color():
    p = Part("widget")
    p.add(_f("base_plate", "add"))
    p.add(_f("vent_holes", "cut"))
    m = p.manifest()
    assert [row["id"] for row in m] == ["base_plate", "vent_holes"]
    assert m[0]["kind"] == "add" and m[1]["kind"] == "cut"
    assert all(row["colorHex"].startswith("#") and len(row["colorHex"]) == 7 for row in m)
    # name present
    assert m[0]["name"] == "Base Plate"

def test_explicit_color_pin_wins():
    p = Part("widget")
    p.add(_f("base_plate", "add", color="#abcdef"))
    assert p.manifest()[0]["colorHex"] == "#ABCDEF"

def test_validate_rejects_duplicate_ids():
    p = Part("widget")
    p.add(_f("dup", "add"))
    p.add(_f("dup", "cut"))
    with pytest.raises(FeatureValidationError) as exc:
        p.validate()
    assert "dup" in str(exc.value)

def test_validate_rejects_bad_kind():
    p = Part("widget")
    p.add(_f("x", "blend"))  # not add/cut
    with pytest.raises(FeatureValidationError) as exc:
        p.validate()
    assert "kind" in str(exc.value) and "x" in str(exc.value)

def test_validate_rejects_bad_slug_and_empty_name():
    p = Part("widget")
    p.add(Feature(id="Bad Id", name="x", kind="add", build=lambda: None))
    with pytest.raises(FeatureValidationError):
        p.validate()
    p2 = Part("widget")
    p2.add(Feature(id="ok", name="  ", kind="add", build=lambda: None))
    with pytest.raises(FeatureValidationError):
        p2.validate()

def test_validate_rejects_empty_part():
    with pytest.raises(FeatureValidationError):
        Part("widget").validate()

def test_validate_requires_at_least_one_add():
    p = Part("widget")
    p.add(_f("only_a_hole", "cut"))
    with pytest.raises(FeatureValidationError):
        p.validate()

def test_manifest_calls_validate():
    p = Part("widget")
    p.add(_f("dup", "add"))
    p.add(_f("dup", "add"))
    with pytest.raises(FeatureValidationError):
        p.manifest()
```

- [ ] **Step 2: Run test to verify it fails**

Run: `python -m pytest tools/featurekit/tests/test_model.py -v`
Expected: FAIL — `ModuleNotFoundError: No module named 'featurekit.model'`.

- [ ] **Step 3: Write minimal implementation**

`tools/featurekit/featurekit/model.py`:

```python
"""Feature/Part model + the generation-time naming-rigor gate."""
from __future__ import annotations

from dataclasses import dataclass, field
from typing import Any, Callable

from featurekit.color import feature_color, normalize_hex
from featurekit.naming import NamingError, validate_slug

KINDS = ("add", "cut")

class FeatureValidationError(NamingError):
    """Raised when a part's feature list violates the naming-rigor invariants."""

@dataclass
class Feature:
    id: str
    name: str
    kind: str
    build: Callable[[], Any]
    color: str | None = None

def resolved_color(feature: Feature) -> str:
    if feature.color is not None:
        return normalize_hex(feature.color)
    return feature_color(feature.id)

class Part:
    def __init__(self, name: str) -> None:
        self.name = name
        self.features: list[Feature] = []

    def add(self, feature: Feature) -> Feature:
        self.features.append(feature)
        return feature

    def validate(self) -> None:
        if not self.features:
            raise FeatureValidationError(f"part {self.name!r} has no features")
        seen: set[str] = set()
        adds = 0
        for f in self.features:
            try:
                validate_slug(f.id, field="id")
            except NamingError as exc:
                raise FeatureValidationError(str(exc)) from exc
            if not isinstance(f.name, str) or not f.name.strip():
                raise FeatureValidationError(f"feature {f.id!r} has empty name")
            if f.kind not in KINDS:
                raise FeatureValidationError(
                    f"feature {f.id!r} kind {f.kind!r} must be one of {KINDS}"
                )
            if f.id in seen:
                raise FeatureValidationError(f"duplicate feature id {f.id!r}")
            seen.add(f.id)
            if f.color is not None:
                normalize_hex(f.color)  # raises ValueError on bad pin
            if f.kind == "add":
                adds += 1
        if adds == 0:
            raise FeatureValidationError(
                f"part {self.name!r} has no 'add' features — nothing printable"
            )

    def manifest(self) -> list[dict]:
        self.validate()
        return [
            {"id": f.id, "name": f.name.strip(), "kind": f.kind, "colorHex": resolved_color(f)}
            for f in self.features
        ]
```

`tools/featurekit/featurekit/__init__.py` (replace contents):

```python
"""featurekit — feature-first CAD: one feature list -> fused part + colored feature view."""

from featurekit.model import Feature, FeatureValidationError, Part, resolved_color
from featurekit.naming import NamingError, validate_slug
from featurekit.color import PALETTE, feature_color, normalize_hex

__all__ = [
    "Feature", "Part", "FeatureValidationError", "resolved_color",
    "NamingError", "validate_slug",
    "PALETTE", "feature_color", "normalize_hex",
]
```

- [ ] **Step 4: Run test to verify it passes**

Run: `python -m pytest tools/featurekit/tests/test_model.py -v`
Expected: PASS (all cases).

- [ ] **Step 5: Commit**

```bash
git add tools/featurekit/featurekit/model.py tools/featurekit/featurekit/__init__.py tools/featurekit/tests/test_model.py
git commit -m "feat(featurekit): Feature/Part model + naming-rigor gate"
```

---

### Task 5: Manifest sidecar (`.features.step.js`) emission

**Files:**
- Create: `tools/featurekit/featurekit/sidecar.py`
- Modify: `tools/featurekit/featurekit/__init__.py` (export `render_sidecar`, `write_sidecar`)
- Test: `tools/featurekit/tests/test_sidecar.py`

**Interfaces:**
- Consumes: `Part.manifest()` (Task 4).
- Produces:
  - `render_sidecar(part: Part, *, step_path: str) -> str` — returns the `.features.step.js` ES-module text. `step_path` is workspace-relative POSIX. Embeds `manifest.schemaVersion = 1`, `manifest.step.path`, `manifest.features`, and view defaults `{ colorMode: "diagnostic", ghostCutters: true }`.
  - `write_sidecar(part: Part, *, features_step_path: Path) -> Path` — writes `<stem>.step.js` next to the features STEP and returns its path; computes the embedded `step.path` as the features STEP path relative to repo root if possible, else its name.

- [ ] **Step 1: Write the failing test**

`tools/featurekit/tests/test_sidecar.py`:

```python
import json
import re
from pathlib import Path

from featurekit.model import Feature, Part
from featurekit.sidecar import render_sidecar, write_sidecar

def _part():
    p = Part("widget")
    p.add(Feature(id="base_plate", name="Base plate", kind="add", build=lambda: None))
    p.add(Feature(id="vent_holes", name="Vent holes", kind="cut", build=lambda: None))
    return p

def _extract_default_object(js: str) -> dict:
    # The sidecar embeds its manifest as a JSON blob in a marked comment for testability.
    m = re.search(r"/\*FEATUREKIT_JSON\n(.*?)\nFEATUREKIT_JSON\*/", js, re.S)
    assert m, "sidecar must embed a FEATUREKIT_JSON block"
    return json.loads(m.group(1))

def test_render_sidecar_is_es_module_with_manifest():
    js = render_sidecar(_part(), step_path="models/widget.features.step")
    assert "export default" in js
    data = _extract_default_object(js)
    assert data["manifest"]["schemaVersion"] == 1
    assert data["manifest"]["step"]["path"] == "models/widget.features.step"
    feats = data["manifest"]["features"]
    assert [f["id"] for f in feats] == ["base_plate", "vent_holes"]
    assert feats[1]["kind"] == "cut"
    assert data["view"]["ghostCutters"] is True
    assert data["view"]["colorMode"] == "diagnostic"

def test_write_sidecar_writes_named_file(tmp_path):
    step = tmp_path / "widget.features.step"
    step.write_text("placeholder", encoding="utf-8")
    out = write_sidecar(_part(), features_step_path=step)
    assert out == tmp_path / "widget.features.step.js"
    assert "export default" in out.read_text(encoding="utf-8")
```

- [ ] **Step 2: Run test to verify it fails**

Run: `python -m pytest tools/featurekit/tests/test_sidecar.py -v`
Expected: FAIL — `ModuleNotFoundError: No module named 'featurekit.sidecar'`.

- [ ] **Step 3: Write minimal implementation**

`tools/featurekit/featurekit/sidecar.py`:

```python
"""Emit the .features.step.js manifest sidecar the viewer's legend panel reads."""
from __future__ import annotations

import json
from pathlib import Path

from featurekit.model import Part

def _payload(part: Part, *, step_path: str) -> dict:
    return {
        "manifest": {
            "schemaVersion": 1,
            "step": {"path": step_path},
            "features": part.manifest(),
        },
        "view": {"colorMode": "diagnostic", "ghostCutters": True},
    }

def render_sidecar(part: Part, *, step_path: str) -> str:
    data = _payload(part, step_path=step_path)
    blob = json.dumps(data, indent=2)
    # Embed a machine-readable JSON block (for tooling/tests) plus the live ES export.
    return (
        "// Generated by featurekit. Do not edit by hand.\n"
        "/*FEATUREKIT_JSON\n" + blob + "\nFEATUREKIT_JSON*/\n"
        "export default " + blob + ";\n"
    )

def _repo_relative_posix(path: Path) -> str:
    resolved = path.resolve()
    # Walk up looking for the repo root (a .git dir); fall back to the file name.
    for parent in [resolved, *resolved.parents]:
        if (parent / ".git").exists():
            try:
                return resolved.relative_to(parent).as_posix()
            except ValueError:
                break
    return resolved.name

def write_sidecar(part: Part, *, features_step_path: Path) -> Path:
    features_step_path = Path(features_step_path)
    step_rel = _repo_relative_posix(features_step_path)
    js = render_sidecar(part, step_path=step_rel)
    out = features_step_path.with_suffix(features_step_path.suffix + ".js")
    out.write_text(js, encoding="utf-8")
    return out
```

Add to `tools/featurekit/featurekit/__init__.py` imports and `__all__`:

```python
from featurekit.sidecar import render_sidecar, write_sidecar
```

(append `"render_sidecar", "write_sidecar"` to `__all__`.)

- [ ] **Step 4: Run test to verify it passes**

Run: `python -m pytest tools/featurekit/tests/test_sidecar.py -v`
Expected: PASS.

- [ ] **Step 5: Commit**

```bash
git add tools/featurekit/featurekit/sidecar.py tools/featurekit/featurekit/__init__.py tools/featurekit/tests/test_sidecar.py
git commit -m "feat(featurekit): manifest sidecar emission"
```

---

### Task 6: Geometry adapter — `solid()` and `feature_view()` (build123d)

**Files:**
- Create: `tools/featurekit/featurekit/geometry.py`
- Modify: `tools/featurekit/featurekit/__init__.py` (export `solid`, `feature_view`)
- Test: `tools/featurekit/tests/test_geometry.py`

**Interfaces:**
- Consumes: `Part`/`Feature`/`resolved_color` (Task 4); cadpy `label_shape` and build123d at runtime.
- Produces:
  - `solid(part: Part) -> Any` — validates, fuses all `add` builds, subtracts all `cut` builds, returns one build123d `Part`/`Solid`. Label = `part.name`.
  - `feature_view(part: Part) -> list[Any]` — validates; returns a list of build123d solids, one per feature, each labeled with `feature.id` and colored: adds at alpha 1.0, cuts at alpha 0.35 (the ghost). Suitable as the `children` return of a `gen_step()`.
  - `_b123d_color(hex_str: str, alpha: float)` helper.

Geometry tests are guarded with `pytest.importorskip("build123d")` so they skip when build123d is absent (as in the current local env).

- [ ] **Step 1: Write the failing test**

`tools/featurekit/tests/test_geometry.py`:

```python
import pytest

pytest.importorskip("build123d")
from build123d import Box, Cylinder, Pos  # noqa: E402

from featurekit.geometry import feature_view, solid  # noqa: E402
from featurekit.model import Feature, Part  # noqa: E402

def _part():
    p = Part("widget")
    p.add(Feature(id="base_plate", name="Base plate", kind="add",
                  build=lambda: Box(20, 20, 4)))
    p.add(Feature(id="vent_hole", name="Vent hole", kind="cut",
                  build=lambda: Pos(0, 0, 0) * Cylinder(3, 10)))
    return p

def test_solid_is_single_solid_with_hole_removed():
    s = solid(_part())
    # one fused solid
    assert len(s.solids()) == 1
    # volume is plate minus the bored cylinder (cylinder spans the 4mm plate)
    plate_vol = 20 * 20 * 4
    assert s.volume < plate_vol
    assert s.label == "widget"

def test_feature_view_has_labeled_colored_bodies():
    bodies = feature_view(_part())
    assert [b.label for b in bodies] == ["base_plate", "vent_hole"]
    add_body, cut_body = bodies
    # alpha encodes add vs cut (1.0 vs 0.35)
    assert float(add_body.color.alpha) == pytest.approx(1.0, abs=1e-6)
    assert float(cut_body.color.alpha) == pytest.approx(0.35, abs=1e-6)
```

- [ ] **Step 2: Run test to verify it fails (or skips without build123d)**

Run: `python -m pytest tools/featurekit/tests/test_geometry.py -v`
Expected (no build123d installed locally): SKIPPED at collection (`importorskip`). After `pip install -r tools/featurekit/requirements.txt`: FAIL — `ModuleNotFoundError: No module named 'featurekit.geometry'`.

- [ ] **Step 3: Write minimal implementation**

`tools/featurekit/featurekit/geometry.py`:

```python
"""build123d geometry adapter: the two reductions over a feature list."""
from __future__ import annotations

from functools import reduce
from typing import Any

from cadpy import label_shape  # vendored cadpy on sys.path (see tests/conftest.py)

from featurekit.model import Part, resolved_color

def _b123d_color(hex_str: str, alpha: float) -> Any:
    from build123d import Color

    r = int(hex_str[1:3], 16) / 255.0
    g = int(hex_str[3:5], 16) / 255.0
    b = int(hex_str[5:7], 16) / 255.0
    return Color(r, g, b, alpha)

def solid(part: Part) -> Any:
    """Fuse all 'add' solids, subtract all 'cut' solids -> one printable solid."""
    part.validate()
    adds = [f.build() for f in part.features if f.kind == "add"]
    cuts = [f.build() for f in part.features if f.kind == "cut"]
    body = reduce(lambda a, b: a + b, adds)
    if cuts:
        body = reduce(lambda a, b: a - b, cuts, body)
    body.label = part.name
    return body

def feature_view(part: Part) -> list[Any]:
    """One labeled, colored solid per feature; cuts rendered translucent (ghost)."""
    part.validate()
    bodies: list[Any] = []
    for f in part.features:
        shape = f.build()
        alpha = 1.0 if f.kind == "add" else 0.35
        label_shape(shape, f.id, color=_b123d_color(resolved_color(f), alpha))
        bodies.append(shape)
    return bodies
```

Add to `tools/featurekit/featurekit/__init__.py`:

```python
# Geometry adapter is imported lazily to avoid importing build123d at package import.
def __getattr__(name):  # noqa: D401
    if name in {"solid", "feature_view"}:
        from featurekit import geometry
        return getattr(geometry, name)
    raise AttributeError(name)
```

- [ ] **Step 4: Run the tests**

Run: `pip install -r tools/featurekit/requirements.txt`
Then: `python -m pytest tools/featurekit/tests/test_geometry.py -v`
Expected: PASS (both tests). If build123d cannot be installed in this environment, record that as a blocker and leave the tests skipping; do not fake the geometry.

- [ ] **Step 5: Commit**

```bash
git add tools/featurekit/featurekit/geometry.py tools/featurekit/featurekit/__init__.py tools/featurekit/tests/test_geometry.py
git commit -m "feat(featurekit): build123d geometry adapter (solid + feature_view)"
```

---

### Task 7: End-to-end fixture + `generate()` orchestration through the `scripts/step` pipeline

**Files:**
- Create: `tools/featurekit/featurekit/generate.py`
- Create: `tools/featurekit/examples/plate_with_hole.py` (the generic 2-feature fixture — NOT a Mac Mini part)
- Modify: `tools/featurekit/featurekit/__init__.py` (export `generate`)
- Test: `tools/featurekit/tests/test_generate.py`

**Interfaces:**
- Consumes: `solid`/`feature_view` (Task 6), `write_sidecar` (Task 5), `Part` (Task 4).
- Produces:
  - `generate(part: Part, *, stem: Path) -> dict[str, Path]` — writes three artifacts next to `stem`: `<stem>.step` (fused, via cadpy's `export_build123d_step_scene`), `<stem>.features.step` (assembly, via cadpy assembly export of the feature_view children), and `<stem>.features.step.js` (sidecar). Returns `{"part": ..., "features": ..., "sidecar": ...}`. Validates first (fails closed).
  - `examples/plate_with_hole.py` exposes `build_part() -> Part` and a `gen_step()`-style `main()` calling `generate`.

**Implementation note (grounding):** the fused STEP uses `cadpy.step_export.export_build123d_step_scene(shape, output_path, text_to_cad_entry_kind="part", source_path=..., source_hash=...)`. The features STEP wraps the `feature_view()` children in a `build123d.Compound(label=part.name, children=[...])` and exports it the same way with `text_to_cad_entry_kind="assembly"`. `source_hash` may be a fixed sentinel (e.g. `"featurekit"`) since featurekit owns generation rather than the `scripts/step` discovery path.

- [ ] **Step 1: Write the failing test**

`tools/featurekit/tests/test_generate.py`:

```python
import pytest

pytest.importorskip("build123d")

from pathlib import Path  # noqa: E402

from featurekit.generate import generate  # noqa: E402
from examples.plate_with_hole import build_part  # noqa: E402

def test_generate_writes_three_artifacts(tmp_path):
    out = generate(build_part(), stem=tmp_path / "plate")
    assert out["part"].name == "plate.step"
    assert out["features"].name == "plate.features.step"
    assert out["sidecar"].name == "plate.features.step.js"
    for p in out.values():
        assert p.exists() and p.stat().st_size > 0
    # sidecar references the features STEP and lists both features
    js = out["sidecar"].read_text(encoding="utf-8")
    assert "base_plate" in js and "vent_hole" in js

def test_generate_fails_closed_on_bad_names(tmp_path):
    from featurekit.model import Feature, Part
    bad = Part("plate")
    bad.add(Feature(id="Bad Id", name="x", kind="add", build=lambda: None))
    from featurekit.model import FeatureValidationError
    with pytest.raises(FeatureValidationError):
        generate(bad, stem=tmp_path / "plate")
    # no artifacts written
    assert not list(tmp_path.glob("plate*"))
```

`tools/featurekit/examples/plate_with_hole.py`:

```python
"""Generic 2-feature fixture (a plate with a bored hole). Not a Mac Mini part."""
from __future__ import annotations

from pathlib import Path

def build_part():
    from build123d import Box, Cylinder
    from featurekit.model import Feature, Part

    p = Part("plate")
    p.add(Feature(id="base_plate", name="Base plate", kind="add",
                  build=lambda: Box(20, 20, 4)))
    p.add(Feature(id="vent_hole", name="Vent hole", kind="cut",
                  build=lambda: Cylinder(3, 10)))
    return p

def main(stem: str = "models/plate") -> None:
    from featurekit.generate import generate
    generate(build_part(), stem=Path(stem))

if __name__ == "__main__":
    main()
```

- [ ] **Step 2: Run test to verify it fails (or skips without build123d)**

Run: `python -m pytest tools/featurekit/tests/test_generate.py -v`
Expected (no build123d): SKIPPED. With build123d: FAIL — `ModuleNotFoundError: No module named 'featurekit.generate'`.

- [ ] **Step 3: Write minimal implementation**

`tools/featurekit/featurekit/generate.py`:

```python
"""Orchestrate the two reductions + sidecar into three on-disk artifacts."""
from __future__ import annotations

from pathlib import Path

from featurekit.geometry import feature_view, solid
from featurekit.model import Part
from featurekit.sidecar import write_sidecar

def _export_step(shape, output_path: Path, *, entry_kind: str) -> Path:
    from cadpy.step_export import export_build123d_step_scene

    output_path.parent.mkdir(parents=True, exist_ok=True)
    export_build123d_step_scene(
        shape,
        output_path,
        text_to_cad_entry_kind=entry_kind,
        source_path=Path(__file__).name,
        source_hash="featurekit",
    )
    return output_path

def generate(part: Part, *, stem: Path) -> dict[str, Path]:
    part.validate()  # fail closed before any write
    stem = Path(stem)

    from build123d import Compound

    part_solid = solid(part)
    view_children = feature_view(part)
    view_compound = Compound(label=part.name, children=view_children)

    part_step = _export_step(part_solid, stem.with_suffix(".step"), entry_kind="part")
    features_step = _export_step(
        view_compound, stem.with_name(stem.name + ".features.step"), entry_kind="assembly"
    )
    sidecar = write_sidecar(part, features_step_path=features_step)
    return {"part": part_step, "features": features_step, "sidecar": sidecar}
```

Add `generate` to the lazy `__getattr__` set in `__init__.py` (alongside `solid`, `feature_view`).

- [ ] **Step 4: Run the tests**

Run: `python -m pytest tools/featurekit/tests/test_generate.py -v`
Expected: PASS with build123d installed (`test_generate_fails_closed_on_bad_names` passes even without geometry because validation raises before the build123d import path is exercised — keep it outside the `importorskip` only if validation runs first; since the module-level `importorskip` skips the whole file without build123d, the fail-closed guarantee is also covered by `test_model.py`). 

- [ ] **Step 5: Verify the artifacts load in the existing pipeline (manual integration check)**

Run:
```bash
PYTHONPATH="$(pwd)/.agents/skills/cad/scripts/packages/cadpy/src:$(pwd)/tools/featurekit" \
  python tools/featurekit/examples/plate_with_hole.py
```
Expected: writes `models/plate.step`, `models/plate.features.step`, `models/plate.features.step.js`. Then hand `models/plate.features.step` to the running CAD Viewer (`http://127.0.0.1:<port>/?dir=<abs>&file=plate.features.step`) and confirm two distinctly colored bodies with labels `base_plate` and `vent_hole`. This artifact is the sample Plan B (the viewer panel) will design against.

- [ ] **Step 6: Commit**

```bash
git add tools/featurekit/featurekit/generate.py tools/featurekit/featurekit/__init__.py tools/featurekit/examples/plate_with_hole.py tools/featurekit/tests/test_generate.py
git commit -m "feat(featurekit): generate() + 2-feature fixture end-to-end"
```

---

### Task 8: Full suite green + docs note

**Files:**
- Modify: `tools/featurekit/README.md` (usage example)
- Test: full suite

**Interfaces:**
- Consumes: everything above.
- Produces: a passing `pytest` run and a documented usage path.

- [ ] **Step 1: Run the whole suite**

Run: `python -m pytest tools/featurekit/tests -v`
Expected: pure-core tests PASS; geometry/generate tests PASS if build123d installed, else SKIPPED with a clear reason. No failures.

- [ ] **Step 2: Add a usage example to the README**

Append to `tools/featurekit/README.md`:

```markdown
## Usage

```python
from pathlib import Path
from build123d import Box, Cylinder
from featurekit import Feature, Part, generate

p = Part("plate")
p.add(Feature(id="base_plate", name="Base plate", kind="add", build=lambda: Box(20, 20, 4)))
p.add(Feature(id="vent_hole", name="Vent hole", kind="cut", build=lambda: Cylinder(3, 10)))

generate(p, stem=Path("models/plate"))
# -> models/plate.step (fused, printable)
#    models/plate.features.step (colored feature-view assembly)
#    models/plate.features.step.js (legend manifest sidecar)
```
```

- [ ] **Step 3: Commit**

```bash
git add tools/featurekit/README.md
git commit -m "docs(featurekit): usage example + suite green"
```

---

## Self-Review

**Spec coverage (Modules 0–2 spec):**
- §3.1 Feature Manifest contract → Tasks 2 (slug), 4 (manifest fields/label==id), 5 (sidecar schema). ✅
- §3.2 featurekit dual output → Tasks 6 (solid/feature_view), 7 (generate). ✅
- §3.2 deterministic id→color → Task 3. ✅
- §3.2 naming-rigor gate (fails closed: missing id/name, bad slug, duplicate id, bad kind, non-add-only) → Tasks 2, 4, 7. ✅ (Non-solid-cutter check is deferred — see note below.)
- §5 naming-rigor enforcement (one identity in four places) → label==id (Task 6), manifest id (Task 4/5). ✅
- §3.3 Module 2 viewer panel → **OUT OF SCOPE for this plan** (separate Plan B; this plan emits the sample `plate.features.step` it consumes, Task 7 Step 5). ✅ (intentional split)
- §8 testing: 2-feature generic fixture → Task 7. ✅

**Gaps intentionally deferred (not blocking the engine):**
- *Non-solid cutter rejection* (spec §3.2/§7): requires build123d type checks; add as a follow-up test in `test_geometry.py` once build123d is installed locally (assert a `cut` whose `build()` returns a non-solid raises). Noted here so it is not silently dropped.
- *`features.lock.json` color-lock* (spec §5, optional): not implemented; deterministic `feature_color` already gives cross-run stability, so the lock file is YAGNI until multi-agent color pinning is needed.

**Placeholder scan:** no TBD/TODO; every code step has complete code. ✅

**Type consistency:** `Part.manifest()` returns `list[dict]` with keys `id/name/kind/colorHex` consistently across Tasks 4, 5, 7; `feature_view()` returns labeled solids consumed by `generate()`'s `Compound(children=...)`; `generate()` returns the `{"part","features","sidecar"}` dict asserted in Task 7. ✅

## Execution Handoff

Plan complete and saved to `docs/superpowers/plans/2026-06-19-featurekit-engine.md`.

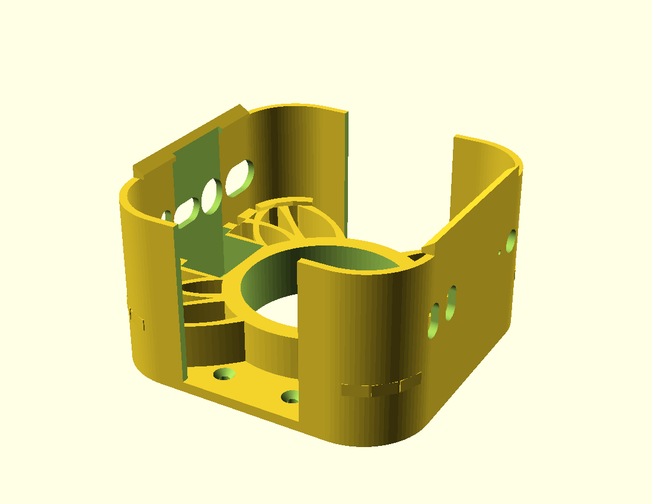
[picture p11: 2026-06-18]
macmini-wall-mount/versions/thumbs/v11_strut-shelves_pbutton-clearance.png

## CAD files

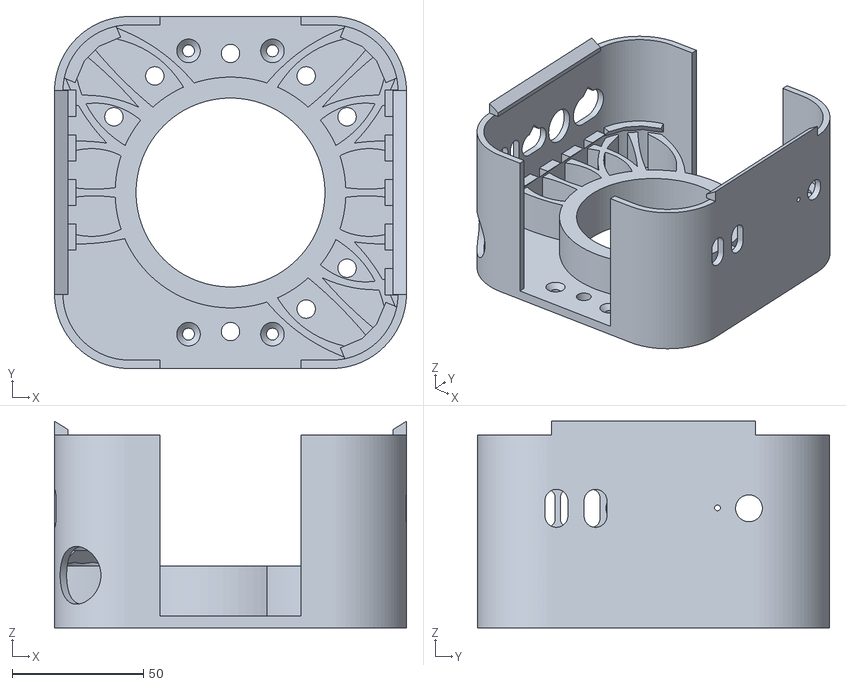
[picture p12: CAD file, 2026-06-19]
macmini-wall-mount/macmini_wall_mount.stl
134.2 x 134.2 x 78.8

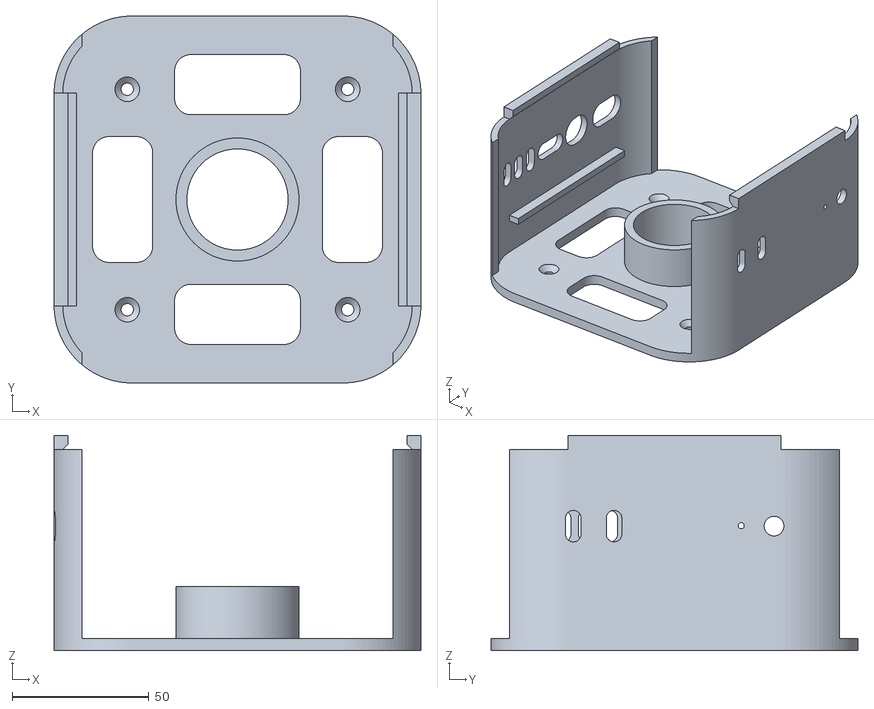
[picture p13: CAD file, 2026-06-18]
macmini-wall-mount/versions/v08_print-in-place_chamfer-catch_round-ports.stl
134.2 x 134.2 x 78.8

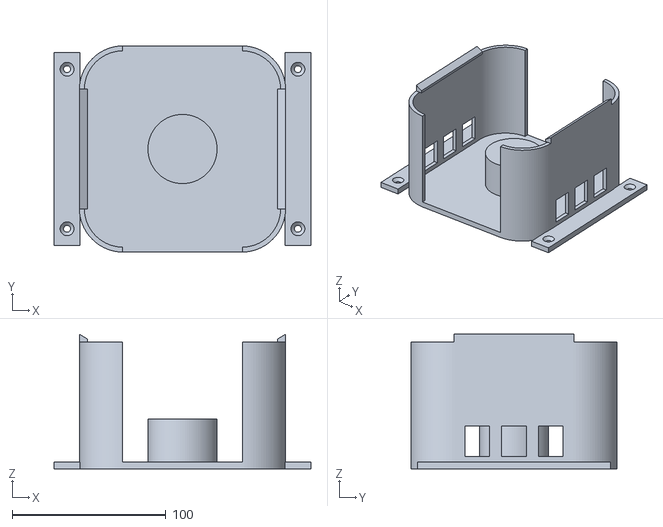
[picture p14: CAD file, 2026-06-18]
macmini-wall-mount/versions/v02_corner-hug_narrow-open.stl
167.2 x 134.2 x 87.7

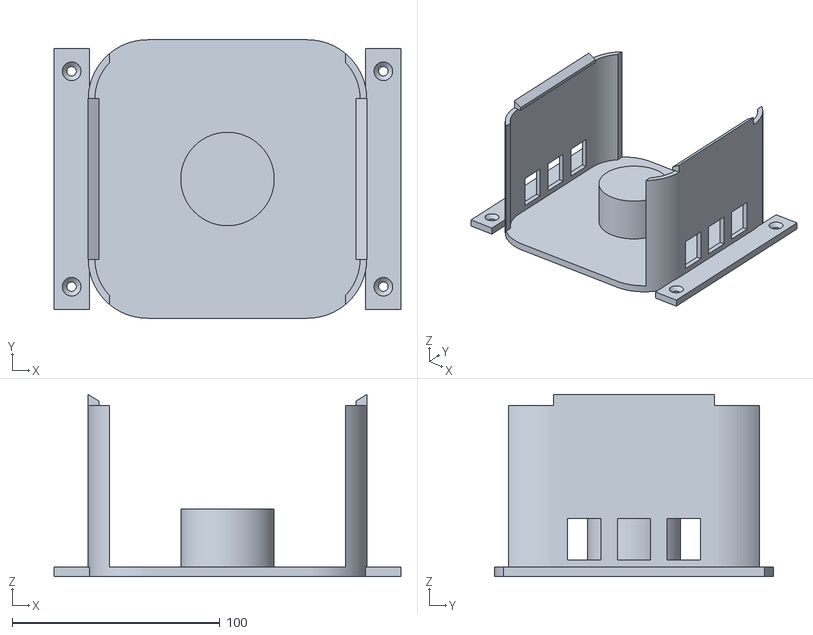
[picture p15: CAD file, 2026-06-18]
macmini-wall-mount/versions/blender_port-traced.stl
167.2 x 134.2 x 87.7

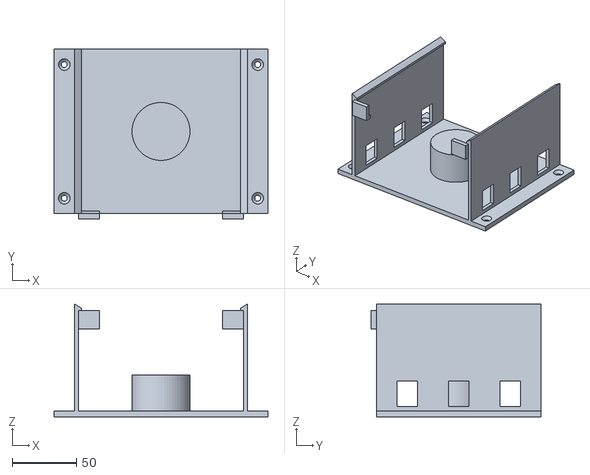
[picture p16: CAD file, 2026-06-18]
macmini-wall-mount/versions/v01_straight-rails_ports-down.stl
166.2 x 131.8 x 87.7

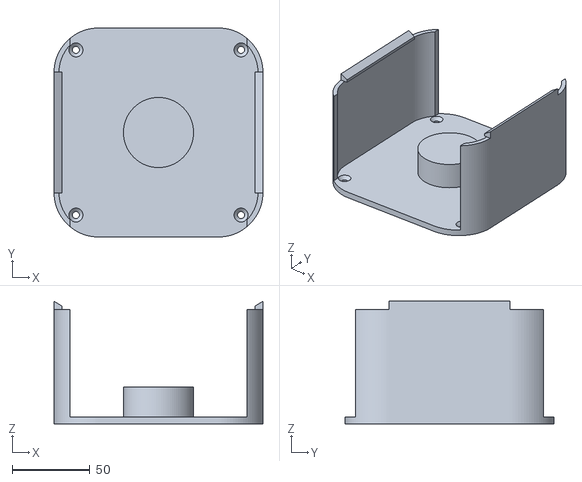
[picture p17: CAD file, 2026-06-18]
macmini-wall-mount/versions/v04_short-spacer_no-vents_min-footprint.stl
134.2 x 134.2 x 78.8

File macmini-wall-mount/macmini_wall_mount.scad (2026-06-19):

// ============================================================
//  Mac Mini (M4 / M4 Pro) Wall Mount  —  parametric, corner-hugging
//  Spec: docs/superpowers/specs/2026-06-17-macmini-wall-mount-design.md
//
//  Orientation (mounted on wall, +Z = out of wall toward room):
//    - Apple-logo (top) face   -> room (+Z)
//    - Bottom face (intake+power button) -> wall, held off by standoff
//    - Back edge (6 ports + exhaust) -> DOWN (-Y), open
//    - Front edge (USB-C + headphone) -> UP (+Y), open
//
//  Retention: four corner pockets conform to the Mini's 25 mm rounded
//  corners and cup them -> they hold the Mini in-plane (incl. its weight)
//  with no separate ledges. Flexible left/right side rails carry snap
//  hooks that retain it in Z. Central standoff sets the air/finger gap.
//  Top & bottom straight edges are left open for the ports + exhaust.
//  Print backplate-down (no supports); material: ASA.
// ============================================================

/* ---------- Mac Mini dimensions (Apple M4/M4 Pro chassis) ---------- */
mini_w   = 127;   // width  (X)
mini_h   = 127;   // height (Y)
mini_t   = 50;    // thickness (Z, wall -> room)
corner_r = 25;    // rounded-corner radius (measured from Macmini.glb; tunable)

/* ---------- Fit / structure ---------- */
fit      = 0.4;   // per-side clearance around the Mini
gap      = 19.05; // back spacer = 3/4 inch (intake gap + power-button access)
back_th  = 4.5;   // backplate thickness
wall_th  = 3.2;   // capture-wall thickness
lip_flat = 2.0;   // flat catch depth of the side snap hooks
screw_x  = 16;    // wall-screw X offset: 2 screws per OPEN top/bottom baseplate segment -> (±screw_x, ±screw_y)
screw_y  = 54;    // wall-screw Y: out in the open ±Y segments (no rib/wall/standoff above) so a driver
                  // has clear vertical access to the countersunk head. (The old corner screws sat
                  // UNDER the diagonal ribs at z=back_th and couldn't be reached to drive.)
ridge_w   = 5;    // rest-ridge protrusion + 45-deg chamfer height (Mini base sits on the top)
ridge_lift = 6;   // raise the rest-ridges ABOVE the spacer's contact plane (z=zmb) by this much.
                  // The Mini's perimeter (where the ridges land) is RECESSED relative to the
                  // central base the 88mm spacer touches, so ridges level with the spacer never
                  // touch. = perimeter recess depth, MEASURED ON THE REAL UNIT (~6mm). The GLB
                  // model under-reported this as 4.66mm (inaccurate); 6mm fits the real Mini.
port_post = 7;    // (legacy) rail end-structure; the top/bottom opening is now governed by
                  // corner_sweep below, not this.
corner_sweep = 12;// how far the top/bottom walls wrap PAST each corner onto the straight edge.
                  // bigger = walls sweep further around the corners (more corner capture).

/* ---------- Wall screws (#8 wood screw / drywall anchor) ---------- */
screw_d  = 4.5;   // shank clearance
head_d   = 9.0;   // countersink head dia
csink    = 2.6;   // countersink depth

/* ---------- Airflow vents in the side rails ---------- */
vent     = false; // airflow vents CLOSED
vent_h   = 16;    // slot height (Y)
vent_z0  = 8;     // slot bottom (Z)
vent_z1  = gap;   // slot top (Z)

$fn = 96;

/* ---------- Derived ---------- */
sw  = mini_w + 2*fit;          // slot width
sh  = mini_h + 2*fit;          // slot height
cr  = corner_r + fit;          // slot corner radius
ow  = sw + 2*wall_th;          // frame outer width
oh  = sh + 2*wall_th;          // frame outer height
orr = cr + wall_th;            // frame outer corner radius
zmb = back_th + gap;           // Mini bottom (intake/wall) face (Z)
zmt = zmb + mini_t;            // Mini top (logo/room) face (Z)
port_z = zmb + 22;             // port band centre: ~22mm above the wall-side face
rx  = sw/2;                    // inner face of side rail (X)
sy  = sh/2 - corner_r;         // half-length of a straight side edge (Y)
ox  = sw/2 - corner_r - corner_sweep;  // half-width of top/bottom opening; wall wraps corner_sweep past each corner
ex  = screw_x;                 // screw X (in the open top/bottom segments)
ey  = screw_y;                 // screw Y (in the open top/bottom segments)

/* ============================================================ */

// 2D rounded rectangle, w x h, corner radius r, centred
module rrect(w, h, r) offset(r) square([w - 2*r, h - 2*r], center = true);

module backplate() {
    // minimized footprint: just the rounded frame body, no protruding screw ears
    linear_extrude(back_th)
        rrect(ow, oh, orr);
}

standoff_d    = 88;        // round spacer outer dia (was 45) — wide central pad reaches the Mini's
                           //   solid base; the perimeter rest-ridges miss it past the cooling vents
standoff_bore = 72;        // central bore pushed wider (37->62->72) to shed more material. Now that the
                           //   join struts are FULL height they carry the structure, so the pad can be a
                           //   thin 8mm ring (r36->44, ~20cm2 contact) + full-height struts that also
                           //   contact the Mini centrally. (~75 dia max: strut roots sit at r37.5.)
lighten       = false;     // lightening windows removed — they clashed with the 88mm pad and worked
                           //   against the added rigidity (set true only if weight matters more)
lighten_d     = 42;        // (unused while lighten = false)

/* ---------- Organic "topology-optimized" join struts: pad -> side rails AND corners ---------- */
join_wall   = true;       // low curved struts fanning from the pad across a wide span of each side rail
join_h      = zmb;        // FULL height (= standoff/bore height): the struts now carry the structure
                          //   the solid pad used to -> far stiffer in bending, replaces material.
                          //   Tops sit at the Mini base plane, adding central contact.
join_n      = 5;          // struts per side rail
join_spread = 34;         // half-span (Y) of rail the fan attaches across (a wide arc of the side wall)
join_t_end  = 5;          // strut thickness where it meets the pad / the rail
join_t_mid  = 2.6;        // thinner mid-span (topology-optimized: material only where it's stressed)
join_bow    = 9;          // organic curvature of the outer struts
join_in     = standoff_d/2 - 4;   // pad-side root radius (fuses into the pad ring)
join_nc     = 3;          // struts per CORNER (organic fan that REPLACES the old thick diagonal rib)
join_corner_arc = 22;     // half-arc (deg) of the corner the corner-fan struts spread across

/* ---------- Support shelves (replace the continuous rest-ledge): one small shelf per strut ---------- */
shelf_len   = 10;         // length of each shelf segment (along the wall) — discrete, sits on a strut
pb_clear    = true;       // finger access to the (wall-facing) power button — through the curved SIDE wall
pb_x        = -47.9;      // power-button centre (harness coords) — from Macmini.glb 'power button' mesh
pb_y        = -47.9;      //   (back/-X side, by the -Y corner); button press-face is at z~29
pb_finger   = 22;         // diameter of the finger hole through the curved corner wall
pb_z        = 20;         // hole-centre height: in the standoff gap, top reaches up to the button (~z29-31)
pb_skip_a   = ((round((atan2(pb_y,pb_x)-45)/90)*90) % 360 + 360) % 360;  // corner fan/shelf to DROP so the
                          // finger cylinder doesn't shred it into junk stubs (=180 for the -X-Y corner)

/* ---------- Airflow vents in the backplate, in the gaps between the struts ---------- */
airflow   = true;
air_r     = 53;           // radius of the vent ring (between the pad r44 and the rails r63.9)
air_d     = 7;            // vent hole diameter
air_ang   = [90, 270, 33, 57, 123, 147, 303, 327];   // angles that fall in the gaps between the fans

module lighten_holes() {
    for (a = [0, 90, 180, 270])
        rotate([0, 0, a]) translate([0, lighten_d, -1])
            linear_extrude(back_th + 2)
                offset(6) square([34, 10], center = true);   // ~46 x 22 rounded window
}

module standoff() {
    // central pad that contacts the Mini's base puck (bored hollow in mount())
    cylinder(h = zmb, d = standoff_d);
}

// Quadratic Bezier point
function bez(p0, p1, p2, t) =
    [ pow(1-t,2)*p0[0] + 2*(1-t)*t*p1[0] + t*t*p2[0],
      pow(1-t,2)*p0[1] + 2*(1-t)*t*p1[1] + t*t*p2[1] ];
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

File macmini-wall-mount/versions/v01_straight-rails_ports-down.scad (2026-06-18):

// ============================================================
//  Mac Mini (M4 / M4 Pro) Wall Mount  —  v01
//  First design: straight L/R capture rails, SHARP (square) corners,
//  back ports exit a rectangular opening on the DOWN edge.
//  Snap hooks on the side rails; bottom corner ledges bear the weight.
// ============================================================
mini_w = 127; mini_h = 127; mini_t = 50;
fit      = 0.4;  gap = 28;  back_th = 4.5;  wall_th = 3.2;  lip_flat = 2.0;  ear = 16;
screw_d  = 4.5;  head_d = 9.0;  csink = 2.6;
corner_sup = 16; sup_th = 4; sup_z = 14;       // bottom corner weight ledges
vent = true; vent_h = 16; vent_z0 = 8; vent_z1 = gap;
$fn = 64;

sw = mini_w + 2*fit;  sh = mini_h + 2*fit;
zmb = back_th + gap;  zmt = zmb + mini_t;  rx = sw/2;
bw = sw + 2*wall_th + 2*ear;  bh = sh;
ex = sw/2 + wall_th + ear/2;  ey = sh/2 - 12;

module backplate() { translate([-bw/2,-bh/2,0]) cube([bw, bh, back_th]); }
module standoff()  { cylinder(h = zmb, d = 45); }

module rail_right() {
    pts = [[rx,0],[rx+wall_th,0],[rx+wall_th, zmt+wall_th+lip_flat],
           [rx-lip_flat, zmt+lip_flat],[rx-lip_flat, zmt],[rx, zmt]];
    translate([0, sh/2, 0]) rotate([90,0,0]) linear_extrude(height = sh) polygon(pts);
}
module rails() { rail_right(); mirror([1,0,0]) rail_right(); }

module support_right() {
    translate([rx-corner_sup, -sh/2-sup_th, zmt-sup_z]) cube([corner_sup, sup_th+0.01, sup_z]);
    translate([rx-corner_sup, -sh/2-sup_th, zmt-sup_z]) cube([corner_sup, sup_th+2, 3]);
}
module supports() { support_right(); mirror([1,0,0]) support_right(); }

module screw_hole() {
    translate([0,0,-1]) cylinder(h = back_th+2, d = screw_d);
    translate([0,0,back_th-csink]) cylinder(h = csink+0.01, d1 = screw_d, d2 = head_d);
}
module vents() {
    for (yy = [-40,0,40])
        translate([rx-4, yy-vent_h/2, vent_z0]) cube([wall_th+8+ear, vent_h, vent_z1-vent_z0]);
}
module mount() {
    difference() {
        union() { backplate(); standoff(); rails(); supports(); }
        for (sx=[-1,1], sy=[-1,1]) translate([sx*ex, sy*ey, 0]) screw_hole();
        if (vent) { vents(); mirror([1,0,0]) vents(); }
    }
}
mount();

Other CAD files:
macmini-wall-mount/versions/v15_airflow-vents_finger-corner-cleanup.stl
macmini-wall-mount/versions/v14_pbutton-side-finger-hole.stl
macmini-wall-mount/versions/v13_pbutton-through-hole.stl
macmini-wall-mount/versions/v10_organic-struts_wide-bore.stl
macmini-wall-mount/versions/v09_chamfered-rest-ridges.stl
macmini-wall-mount/versions/v07_bored-standoff_lightened-plate.stl
macmini-wall-mount/versions/v12_corner-clip-fix_pbutton-pocket.stl
macmini-wall-mount/versions/v11_strut-shelves_pbutton-clearance.stl
macmini-wall-mount/versions/v05_side-ports_led.stl
macmini-wall-mount/versions/v09b_blender-boolean-cut.stl
macmini-wall-mount/versions/v05b_blender-boolean-cut.stl
macmini-wall-mount/versions/v02_corner-hug_narrow-open.scad
macmini-wall-mount/versions/v03_corner-hug_wide-open_screw-ears.scad
macmini-wall-mount/versions/v03_corner-hug_wide-open_screw-ears.stl
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

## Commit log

2026-06-18 Initial commit: Mac Mini M4 parametric wall mount (v01–v12)
    Corner-hugging OpenSCAD wall mount for the Mac Mini M4/M4 Pro: side-rail
    port cutouts, Ø88mm contact pad, organic topology-optimized bracing struts,
    discrete support shelves, and a power-button access pocket. Includes the full
    versioned design history (versions/ + VERSIONS.md + thumbnails) and the
    reference GLB.
    [blender_port-traced.stl, macmini_wall_mount.scad, macmini_wall_mount.stl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]
2026-06-18 v13: power-button through-hole (reachable from behind)
    Button faces the wall and was trapped between the Mini and backplate. pb_cut
    is now a Ø20 through-hole from the back face to the button, clearing the
    backplate plus struts/shelves in that column (pad and corner wall untouched).
    Located from the Macmini.glb 'power button' mesh with the Mini seated in the
    harness; assembly fit-check showed no clipping.
    [v13_pbutton-through-hole.scad, v13_pbutton-through-hole.stl]
2026-06-18 v14: power-button finger hole through the curved corner side wall
    A backplate hole is useless when the mount sits flush to a wall, so the v13
    through-hole is replaced by a finger-sized (Ø22) horizontal channel through the
    exposed curved corner wall, aimed radially at the button and clearing the
    struts/shelves in the path. Backplate stays solid; channel inner end clears the
    central pad; top of the channel reaches the button press-face (z~29).
    [v14_pbutton-side-finger-hole.scad, v14_pbutton-side-finger-hole.stl]
2026-06-19 v15: airflow vents + finger-corner junk cleanup
    - Airflow vents: 8 holes through the backplate in the gaps between the radial
    struts (skips the finger-hole corner).
    - Junk cleanup: the finger cylinder runs along the -X,-Y corner diagonal and
    was shredding that corner's fan into stub fragments; that one corner's fan +
    shelves are now dropped (pb_skip_a auto-derived from the button angle).
    [v15_airflow-vents_finger-corner-cleanup.scad, v15_airflow-vents_finger-corner-cleanup.stl]
2026-06-19 Reorganize Mac Mini wall mount into macmini-wall-mount/
    Move all wall-mount sources, meshes, renders, scripts, the design spec, and
    the versions/ history into a dedicated macmini-wall-mount/ directory. Update
    .gitignore allowlist to track the curated files at their new paths. The
    separate bowstring and power-access-arm projects stay at repo root.
    [blender_port-traced.stl, macmini_wall_mount.scad, macmini_wall_mount.stl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]
2026-06-19 v16: teardrop port tops, thicker webs, clean power-button channel
    Printability fixes on the side-rail ports and the power-button finger hole:
    1. Droopy port overhangs — every port (obround + round) now gets a 45-deg
    teardrop gable on top (teardrop / port_profile2d). Printed back-plate-down,
    the old round/obround tops bridged horizontally and drooped; the gable keeps
    every ceiling face <=45 deg and self-supports. The converging gables also tie
    each thin inter-port web into the solid wall above the band.
    2. Snapped USB-C/Thunderbolt webs — web_min 1.35 -> 2.0 mm. The crowded back-rail
    webs were exactly 1.35 mm (3 perimeters @0.45) and broke in handling; now
    ~2.0 mm (~4-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
    [v16_teardrop-ports_thick-webs_pb-cleanup.scad, v16_teardrop-ports_thick-webs_pb-cleanup.stl]
2026-06-19 Merge parallel ridge_lift change: 4 -> 6 mm (measured on real Mini)
    Picks up the other agent's parallel parameter fix: the rest-ridge lift is the
    Mini's perimeter recess depth, measured ~6 mm on the real unit. The GLB model
    under-reported it as 4.66 mm. Isolated change (only ridge_lift) — no overlap with
    the v16 port/web/power-button edits. STL regenerated (CGAL Volumes: 2).
    [macmini_wall_mount.scad, macmini_wall_mount.stl, v16_teardrop-ports_thick-webs_pb-cleanup.scad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]
2026-06-19 ridge_lift 4 -> 6 mm: perimeter recess measured on the real Mini
    The GLB reference under-reported the Mini's perimeter recess (~4.66 mm); the real
    unit measures ~6 mm, so the rest-ridges need the larger lift to actually contact.
    [macmini_wall_mount.scad, macmini_wall_mount.stl]
2026-06-19 Fix merge-corrupted STL; mark mesh/binary files as binary
    The ASCII STLs were 3-way TEXT-merged during the branch merge (interleaving
    triangles from both sides into an invalid mesh). Regenerated
    macmini_wall_mount.stl from the merged .scad (authoritative, CGAL Volumes: 2) and
    synced the v16 version snapshot.
    Added .gitattributes (with a .gitignore exception so it's tracked) marking
    *.stl/*.glb/*.blend/*.3mf/*.step/*.png as binary, so future merges never
    text-merge a mesh again.
    [macmini_wall_mount.stl, v16_teardrop-ports_thick-webs_pb-cleanup.stl]
2026-06-20 Add feature-first CAD methodology + Modules 0-2 design spec
    Part-separation vs merged-whole methodology report (for parallel-agent
    CAD design with naming-rigor enforcement) and the implementation spec
    for Modules 0-2: Feature Manifest contract, cadpy.featurekit generator
    with naming-rigor gate, and the viewer Feature Legend panel. No
    part-specific (Mac Mini) content.
2026-06-20 Add featurekit engine implementation plan (Modules 0-1)
    TDD, bite-sized tasks for the Python feature-first CAD engine: slug
    naming gate, deterministic id->color, Feature/Part model with the
    naming-rigor gate, manifest sidecar, build123d geometry adapter
    (solid + feature_view), and generate() with a generic 2-feature
    fixture. Viewer panel (Module 2) is a separate plan.
2026-06-20 fix(featurekit): color-pin fails closed as FeatureValidationError; tidy tests/imports
